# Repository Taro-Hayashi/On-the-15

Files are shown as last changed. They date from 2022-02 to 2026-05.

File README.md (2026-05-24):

# On the 15 ビルドガイド（[English](README_EN.md)）
- [キット内容](#キット内容)
- [レイアウトを決める](#レイアウトを決める)
- [はんだ付け](#はんだ付け)
- [組み立て](#組み立て)
- [キーのカスタマイズ](#キーのカスタマイズ)
- [そのほか](#そのほか)

## キット内容
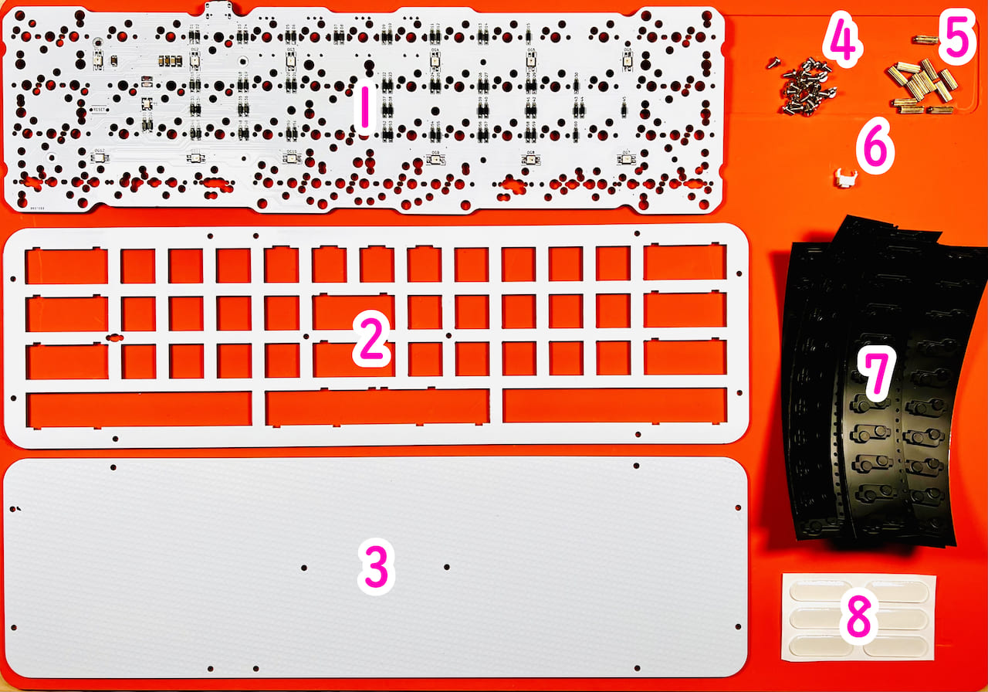
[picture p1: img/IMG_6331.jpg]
  
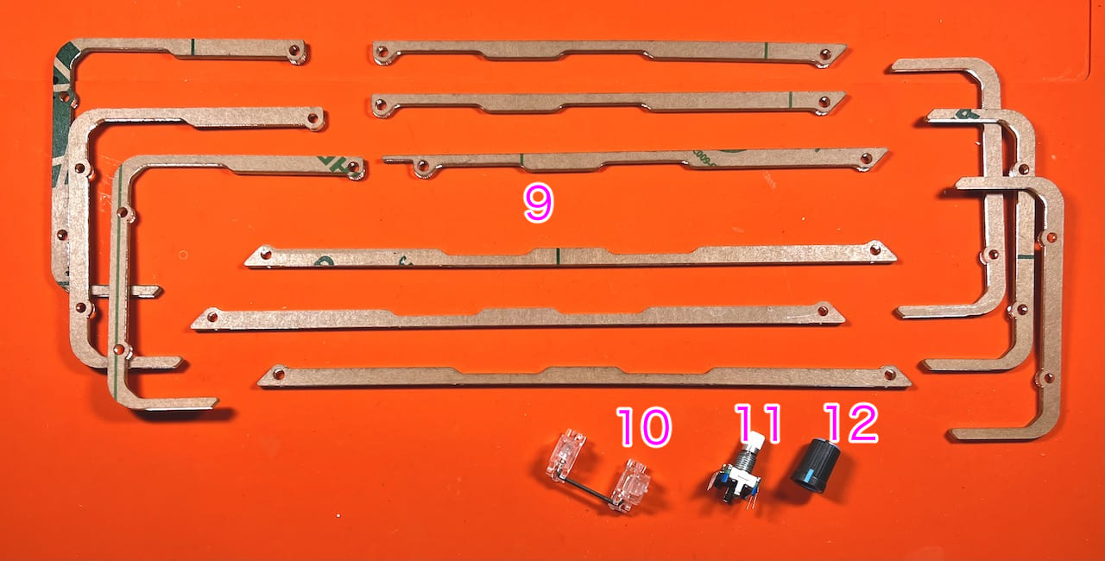
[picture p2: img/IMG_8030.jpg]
  
||部品名|数|
|-|-|-|
|1|メインボード|1|
|2|トッププレート|1|
|3|ボトムプレート|1|
|4|ネジ|22|
|5|スペーサー|11|
|6|リセットスイッチ|1|
|7|Cherry MX ホットスワップソケット|60|
|8|ゴム足|6|
|9|アクリルミドルプレート||
|10|2Uスタビライザー|1|
|11|ロータリーエンコーダー|1|
|12|ノブ|1|

### キット以外に必要なもの
|部品名|数|||
|-|-|-|-|
|キースイッチ|〜60|CherryMX互換|[遊舎工房](https://shop.yushakobo.jp/collections/all-switches/cherry-mx-%E4%BA%92%E6%8F%9B-%E3%82%B9%E3%82%A4%E3%83%83%E3%83%81) / [TALPKEYBOARD](https://talpkeyboard.net/?category_id=59cf8860ed05e668db003f5d) / [DailyCraftKeyboard](https://shop.dailycraft.jp/collections/mx-switches)|
|キーキャップ|〜60|CherryMX互換|[遊舎工房](https://shop.yushakobo.jp/collections/keycaps/cherry-mx-%E4%BA%92%E6%8F%9B-%E3%82%AD%E3%83%BC%E3%82%AD%E3%83%A3%E3%83%83%E3%83%97) / [TALPKEYBOARD](https://talpkeyboard.net/?category_id=59e2acfaed05e644fd004008)|
|Type-C ケーブル|1|||

### 追加できるもの
|部品名|||
|-|-|-|
|色違いアクリルプレート|-|[遊舎工房 - キーボードアクリルプレート](https://shop.yushakobo.jp/collections/services/products/keyboard_acrylic_plate?variant=43949129629927)|
|スタビライザー|2U、PCBマウント|[遊舎工房](https://shop.yushakobo.jp/collections/all-keyboard-parts/Stabilizer) / [TALPKEYBOARD](https://talpkeyboard.net/?category_id=5f884b9b3313d216eb50558a)|
|ロータリーエンコーダ|EC11/EC12/ロープロファイル|[遊舎工房](https://shop.yushakobo.jp/search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) / [TALPKEYBOARD](https://talpkeyboard.net/items/5f3f1a597df28129f2fd4b0f) / [DailyCraftKeyboard](https://shop.dailycraft.jp/products/encoder_low)|
|ノブ|外径19mmまで|[遊舎工房](https://shop.yushakobo.jp/products/3733) / [DailyCraftKeyboard](https://shop.dailycraft.jp/products/encoder_lowprofile_knob)|

専用のアクリルケースもあります。  
- [アクリルケースデータ](acrylic-case/README.md)
  - [fully-acrylic](acrylic-case/fully-acrylic/README.md)
  - [pcb-switchplate](acrylic-case/pcb-switchplate/README.md)

### 必要な工具
|工具名|
|-|
|はんだごて|
|こて先クリーナー（こて台）|
|鉛入りはんだ|
|ピンセット|
|精密ドライバー|

## レイアウトを決める
On the 15は60キーの格子配列キーボードですが、色のついたキーは長さを変更することができます。  
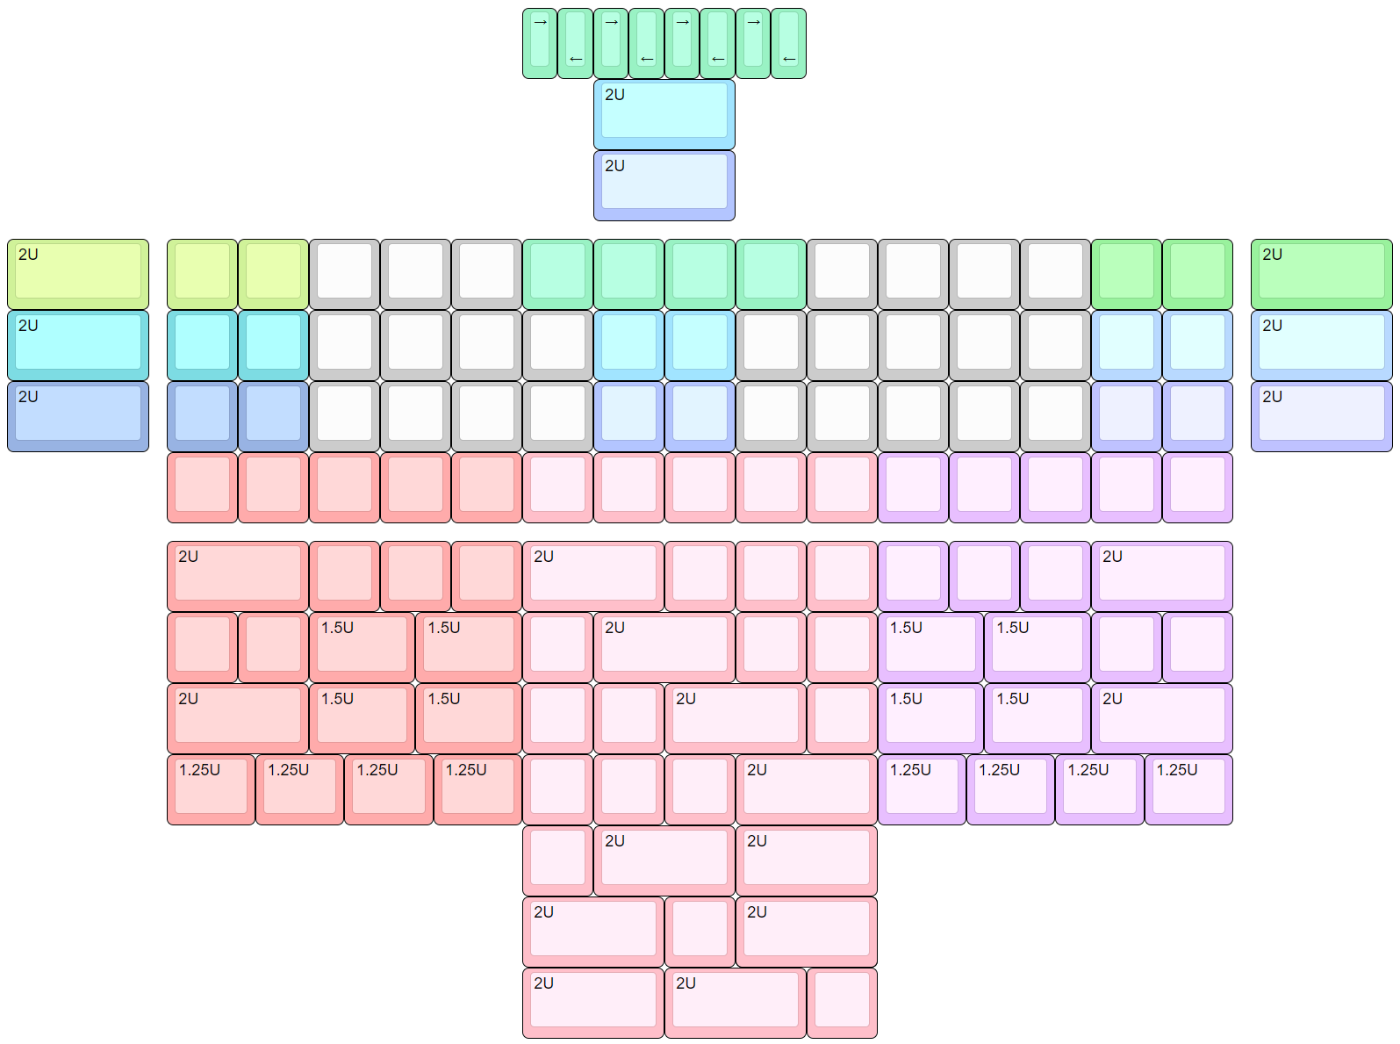
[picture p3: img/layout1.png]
  

ビルドガイドではこのようなレイアウトで組み立てます。　
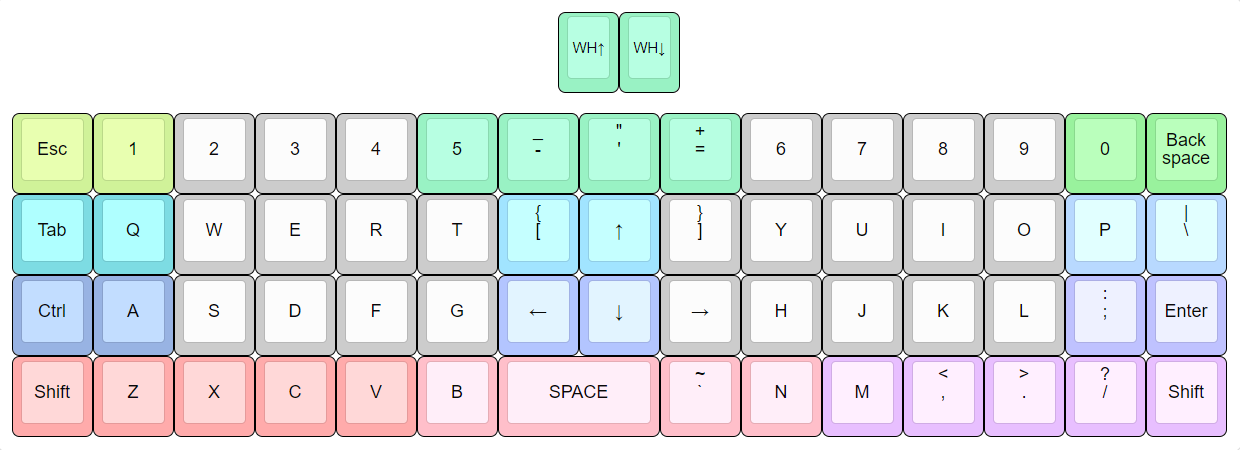
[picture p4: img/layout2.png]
  

## はんだ付け
### ソケットのはんだ付け
使うソケットのパッドに予備はんだをします。  
あらかじめ薄くはんだを乗せます。  
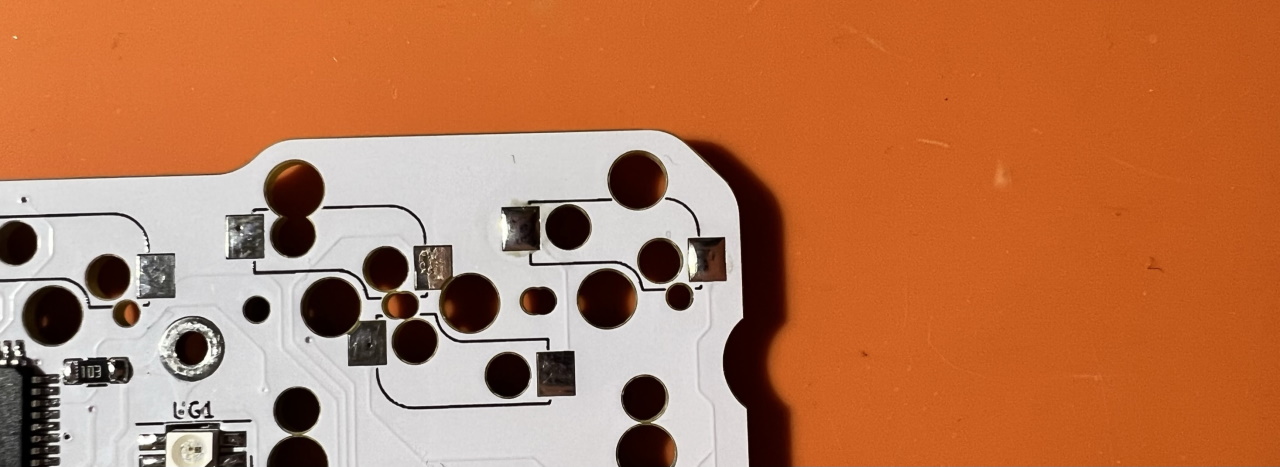
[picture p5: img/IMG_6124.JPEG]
  
ソケットを置いたらピンセットで押さえつけながらはんだを注いでいきます。入り組んでいて表面積が多いので多めに必要になります。
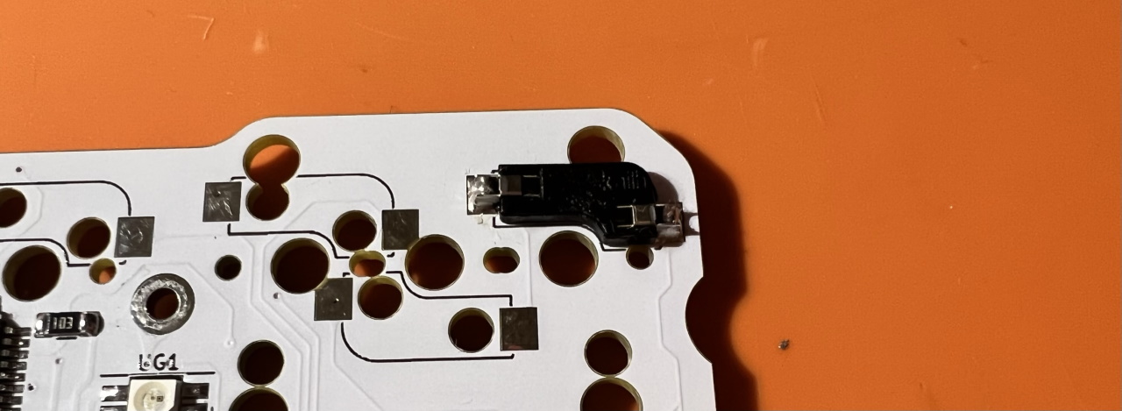
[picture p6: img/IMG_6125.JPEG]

慣れてきたら予備はんだを省略したり、一度に複数個置いてはんだ付けをすると楽になります。  
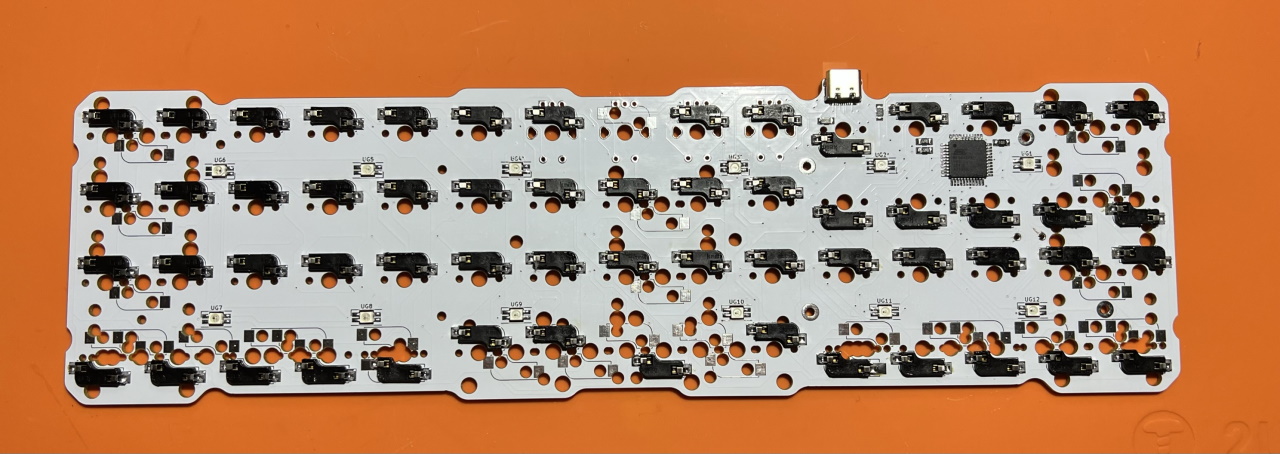
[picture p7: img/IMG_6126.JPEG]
  
### リセットスイッチのはんだ付け
表面左側のRESETと書いてあるところにリセットスイッチを差して裏からはんだ付けします。  
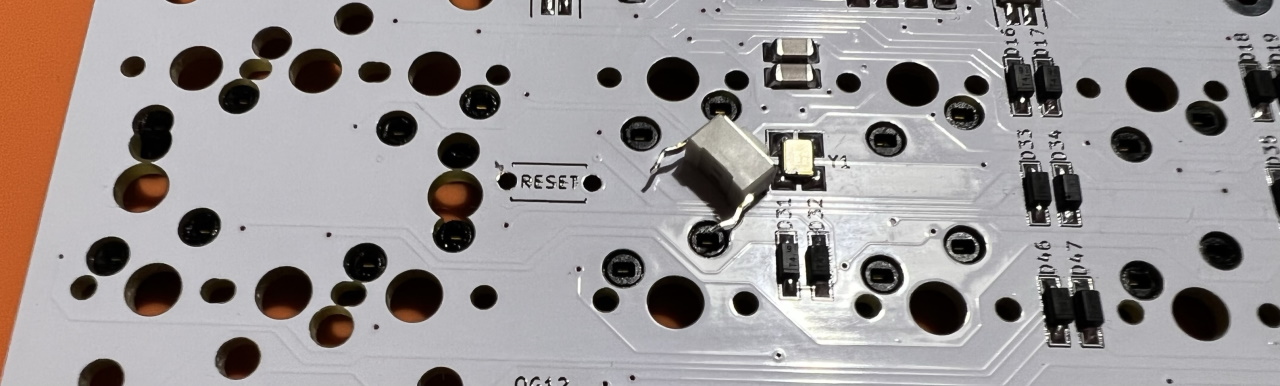
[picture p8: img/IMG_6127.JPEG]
  

### ロータリーエンコーダーのはんだ付け
足を折らないようにホールに通して裏からはんだ付けします。  
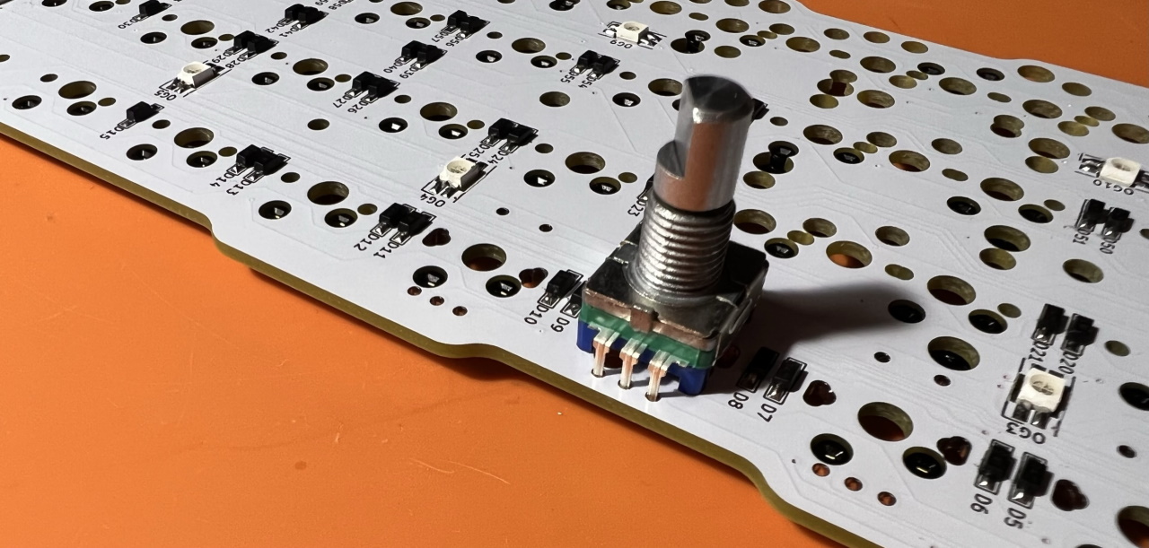
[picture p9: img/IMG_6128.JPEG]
   

### テストファームウェアの書き込み
テスト用のファームウェアをこちらからダウンロードしてください。
- https://remap-keys.app/catalog/9bQPDxdkX8xgflHlsR9p/firmware

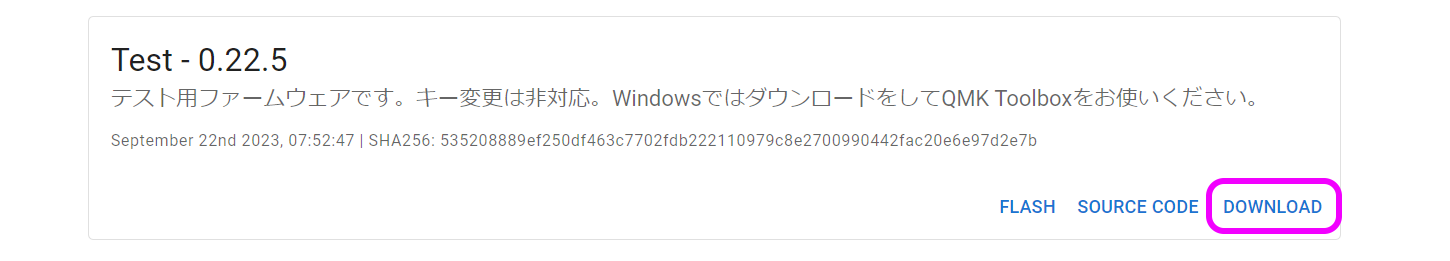
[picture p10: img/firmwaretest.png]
 

QMK Toolboxのreleaseページから最新版をダウンロードしてインストールください。  
- [Releases・qmk/qmk_toolbox](https://github.com/qmk/qmk_toolbox/releases)

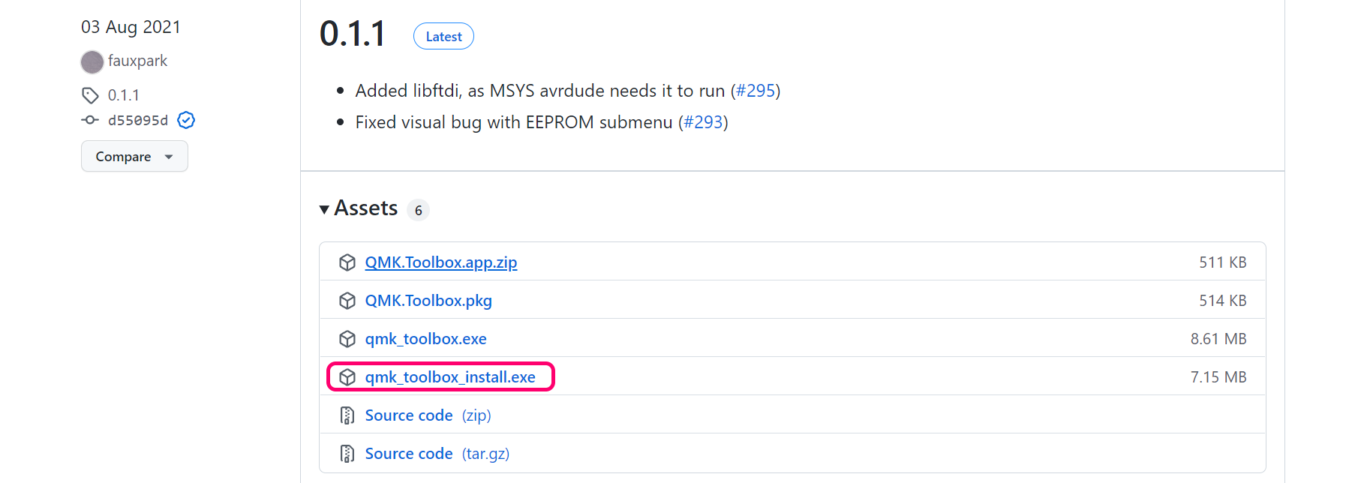
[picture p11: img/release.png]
  
起動したらOpenを押してダウンロードしたファームウェアを指定し、はんだ付けしたリセットボタンを押します。  
   
新しく黄色の文字が出てきたらFlashを押します。  
  

Thank youの後に黄色い文字が出たら更新完了です。  
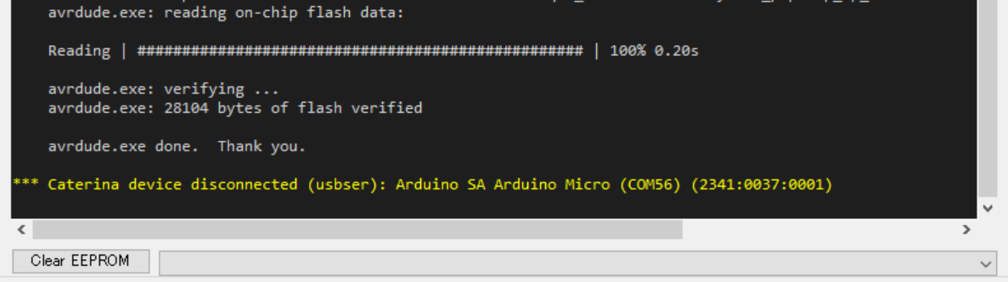
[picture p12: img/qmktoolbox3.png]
   

### 動作確認
キースイッチを差したり裏をピンセットで短絡したりして動作確認をします。  
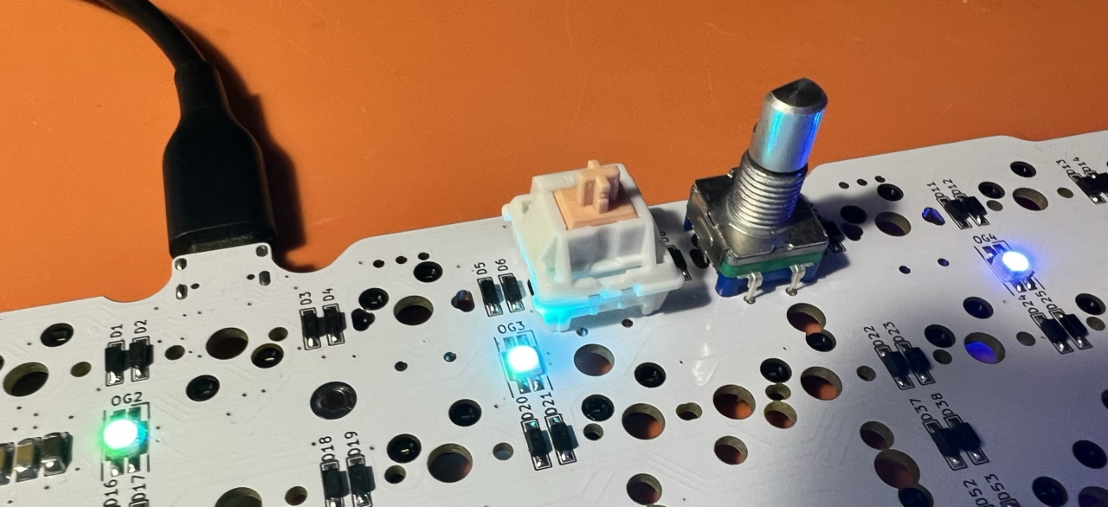
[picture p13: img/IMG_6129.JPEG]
   
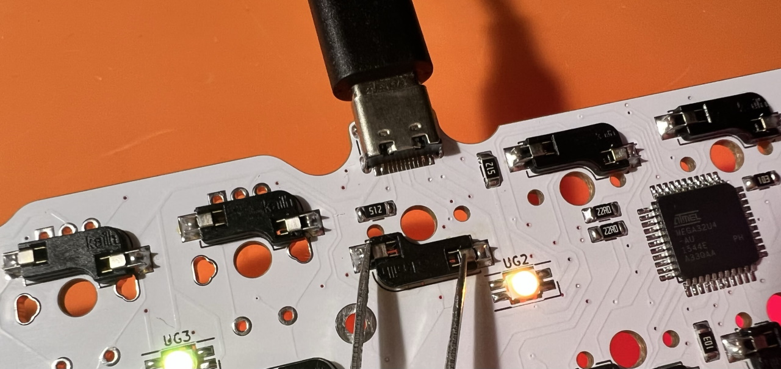
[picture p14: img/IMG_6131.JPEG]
   

## 組み立て
### スタビライザーを組み立てる
スタビライザーがあると2Uのキーの押下が安定します。無くても使えるのでお好みでお使いください。  
ねじ止め式のスタビライザーは縦に二つ並べておくことはできないので使う場所に気をつけるかスナップ型のスタビライザーを使ってください。  

小さい方のパーツの穴が二つ開いている側を、大きいパーツの穴が開いている方向に合わせて組み合わせます。  
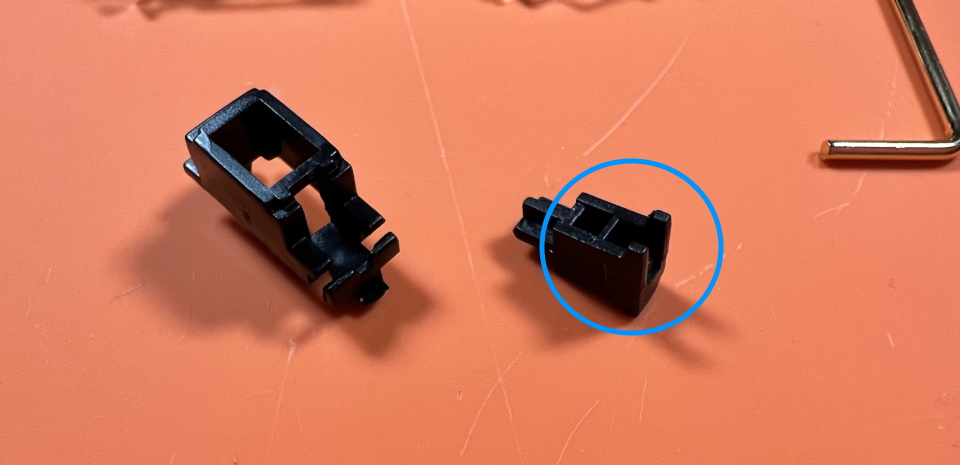
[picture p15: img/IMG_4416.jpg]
  
金属の棒を下の穴に差し込みツメにパチっと音がするまで押し込んで完成です。  
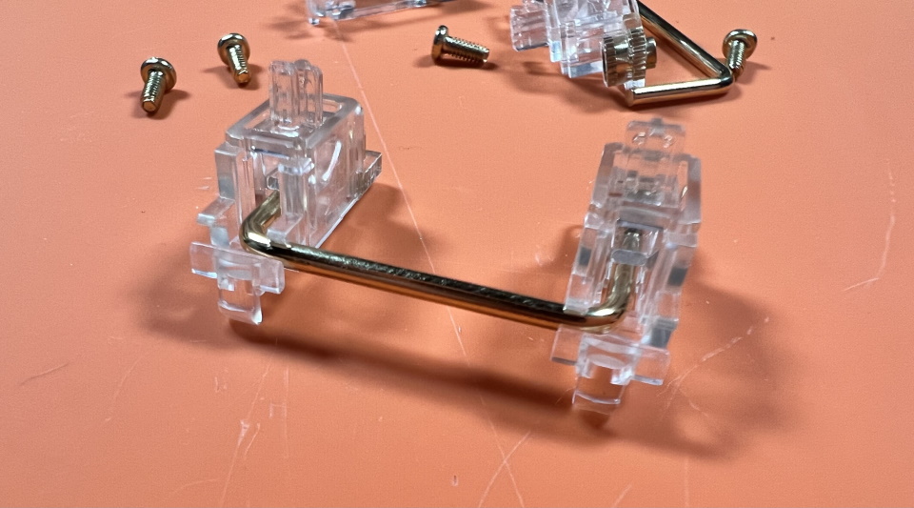
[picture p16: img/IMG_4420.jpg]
    
基板の大きい方の穴にツメをひっかけながら取り付けます。  
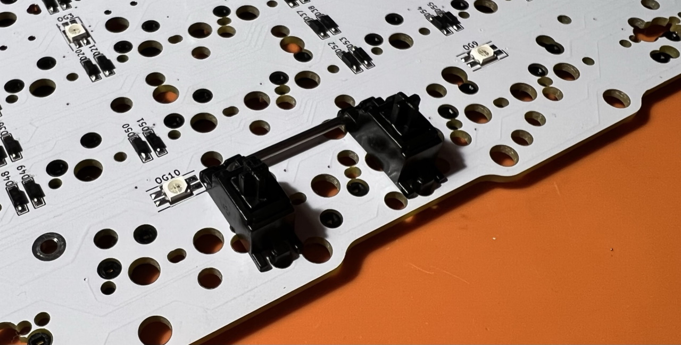
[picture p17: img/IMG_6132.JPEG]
  

### メインボードにトッププレートを取り付ける
トッププレートの裏側にスペーサーをねじ止めします。  
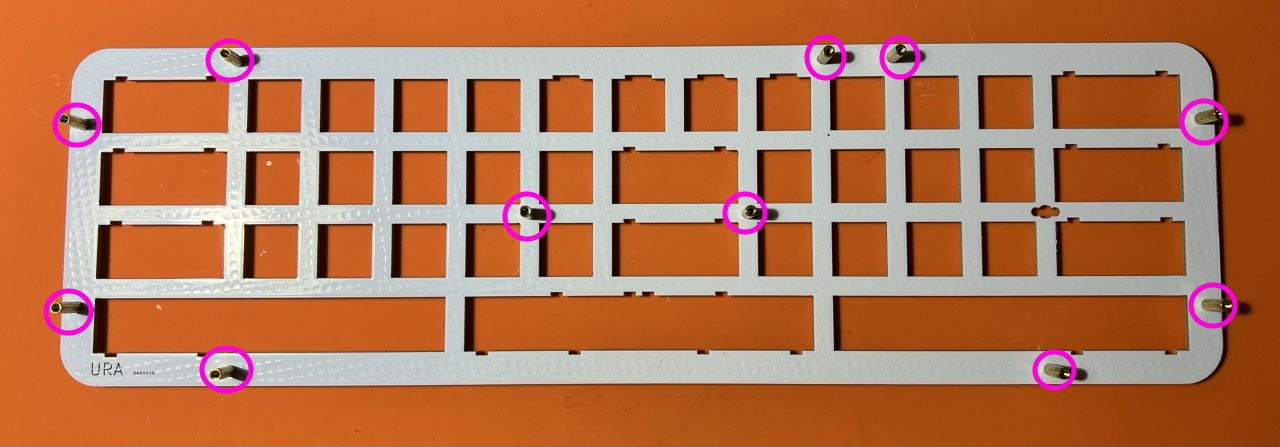
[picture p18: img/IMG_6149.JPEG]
   
メインボードにかぶせて、4隅のスイッチをはめ込みます。  
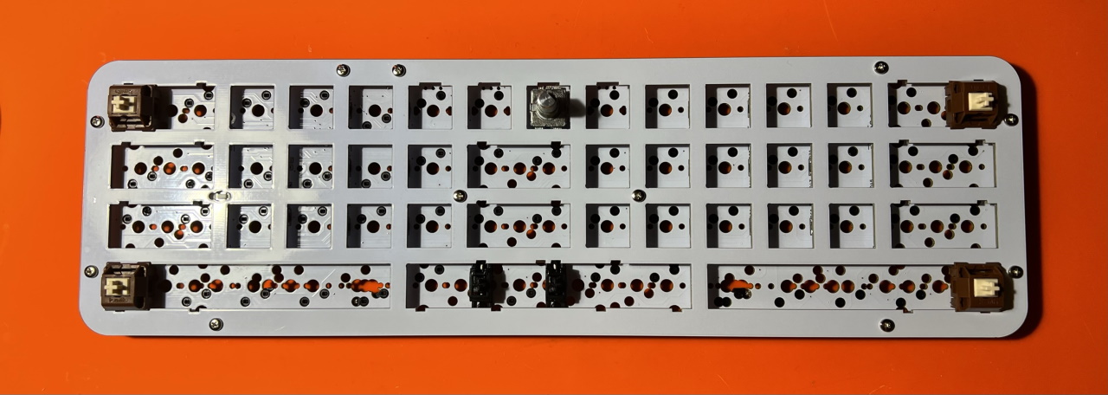
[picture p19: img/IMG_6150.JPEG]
   
すべてのスイッチを差し込みました。  
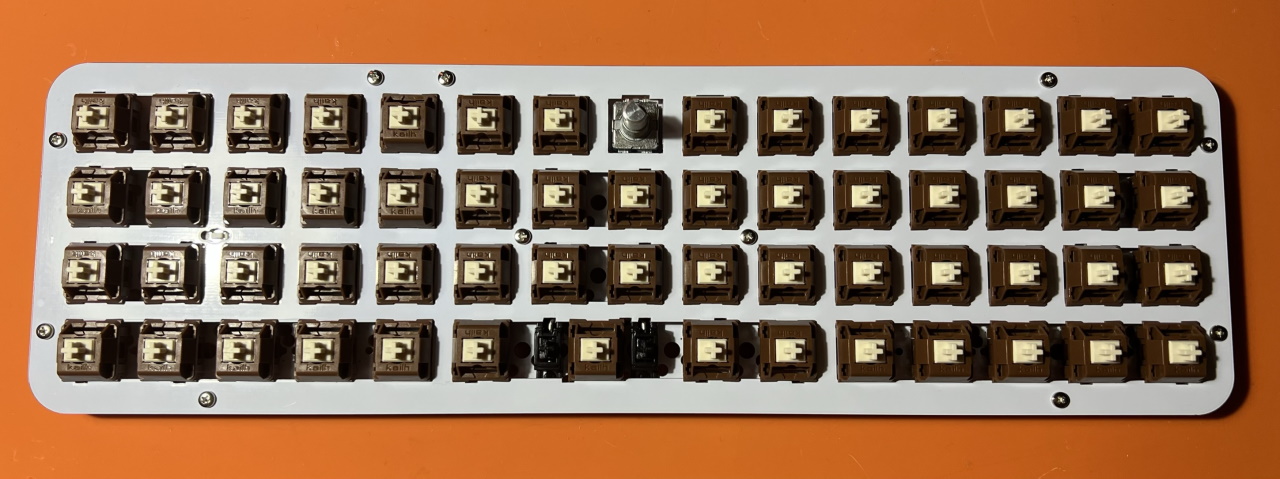
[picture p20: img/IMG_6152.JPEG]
  

### アクリルプレートを挟み込む
画像のような形で3段にして挟み込みます。  
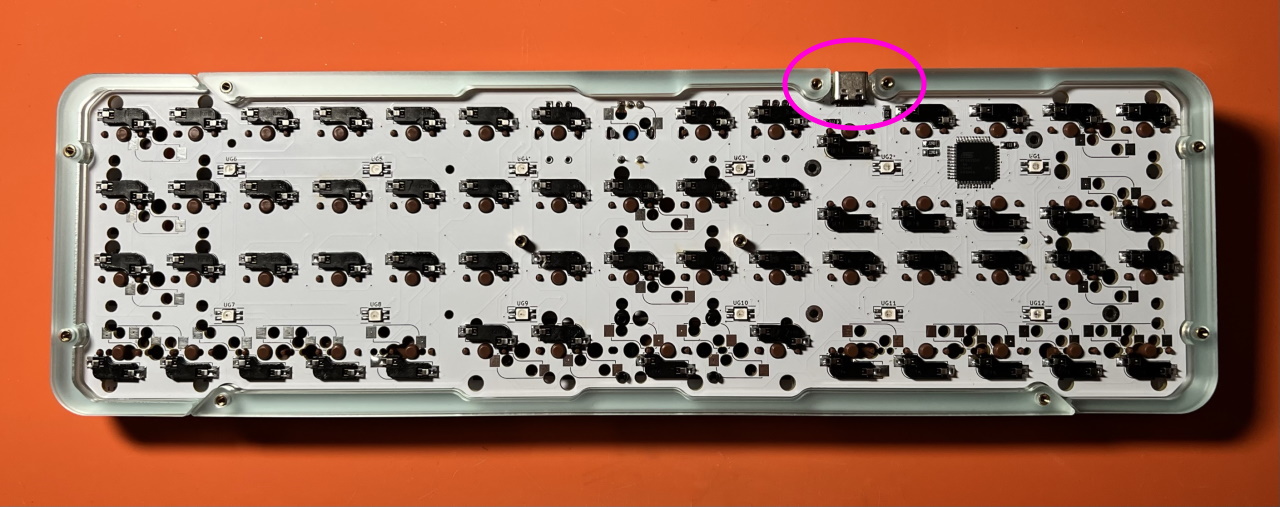
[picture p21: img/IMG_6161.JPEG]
  

### バックプレートを取り付ける
バックプレートをねじ止めしてゴム足を貼ります。  
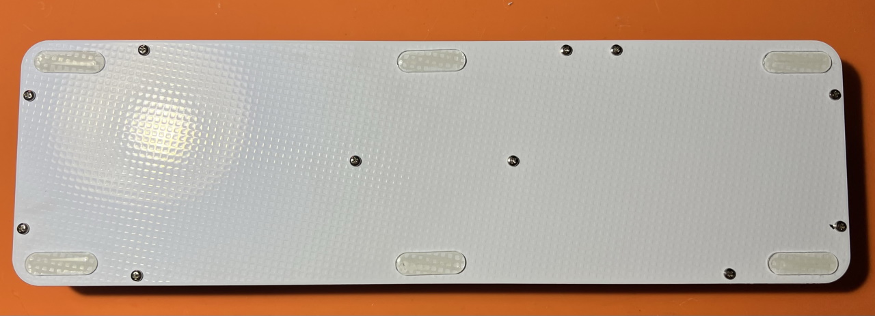
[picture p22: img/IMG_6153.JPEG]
  
キーキャップを付けたら完成です。  
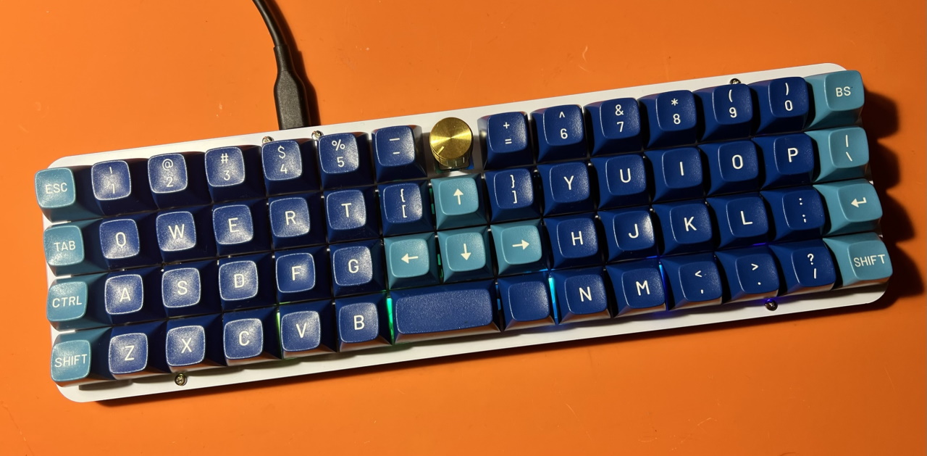
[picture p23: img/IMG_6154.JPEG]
  

### Remap用ファームウェアの書き込み
Remap用のファームウェアをこちらからダウンロードして、さきほどと同様に書き込んでください。
- https://remap-keys.app/catalog/9bQPDxdkX8xgflHlsR9p/firmware

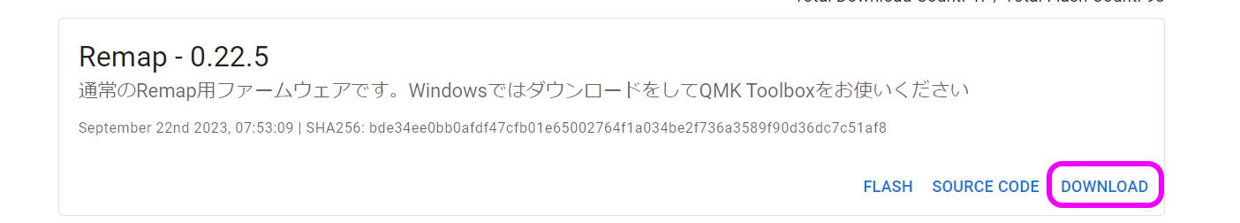
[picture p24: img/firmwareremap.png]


## キーのカスタマイズ
こちらのサイトにアクセスしてください。
- Remap https://remap-keys.app

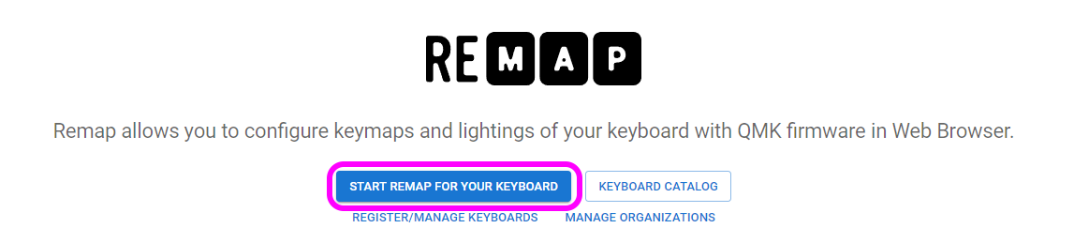
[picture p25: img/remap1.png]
  
左を選んで進んでいくとダイアログが出てキーボードを選択できます。  
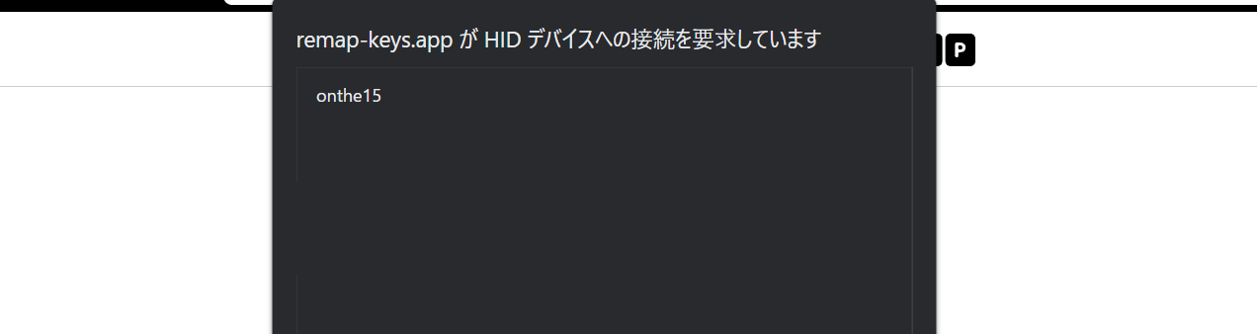
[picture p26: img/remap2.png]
  
選択して接続してください。
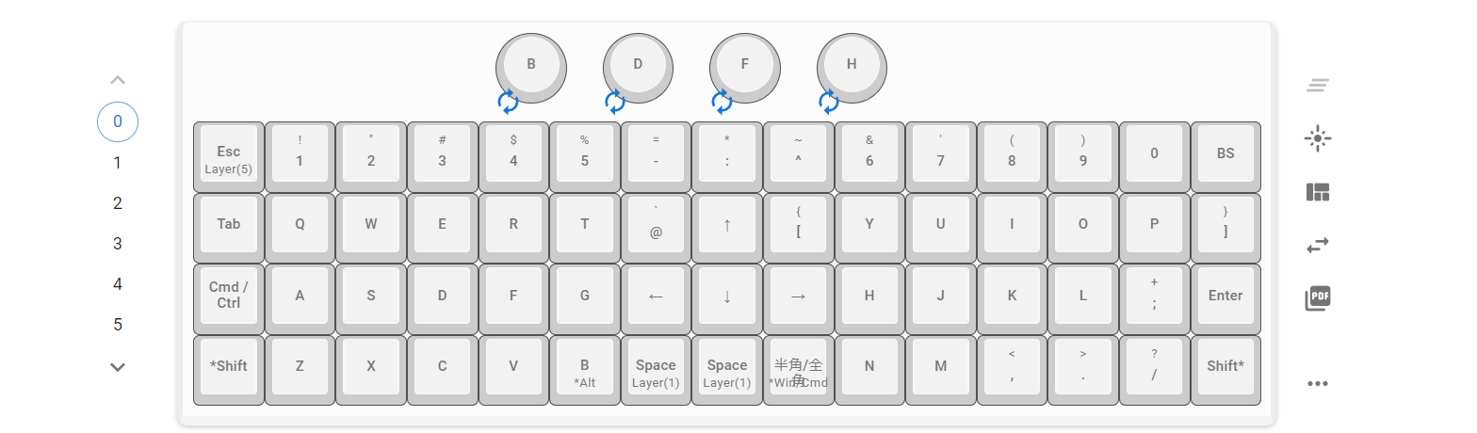
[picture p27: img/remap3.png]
  

### キーマップの保存と復元
⇔アイコンで作ったキーマップを保存することができます。  
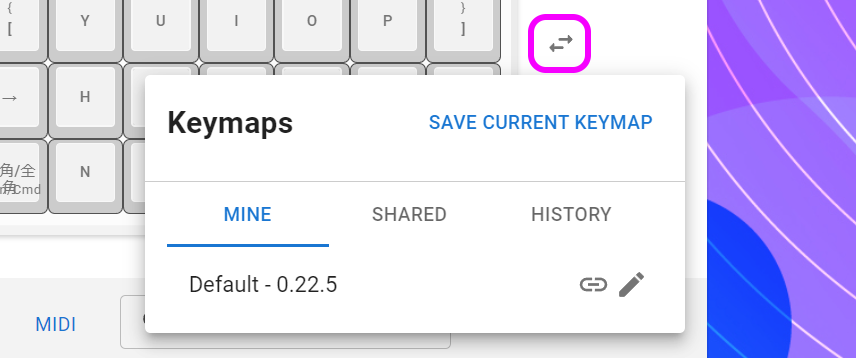
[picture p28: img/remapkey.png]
  
作ったキーマップを共有することもできるので是非お試しください。

### レイアウトを変える
キーボードの右のこのボタンでレイアウトを変えることができます。  
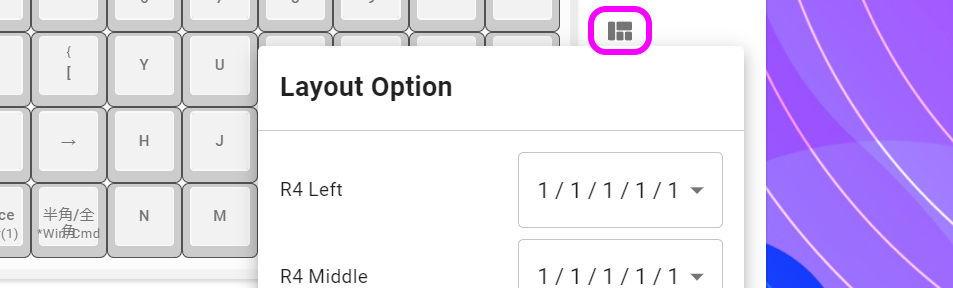
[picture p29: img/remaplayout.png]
  

### キーを設定する
下のキー一覧からドラッグアンドドロップし、変更が終わったら右上のflashボタンを押すと反映されます。  
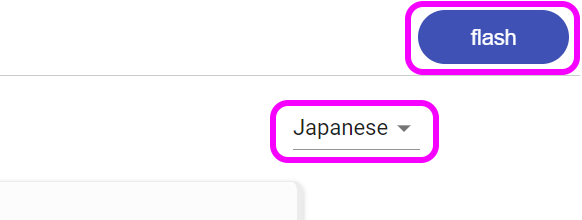
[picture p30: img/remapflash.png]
  
また、USキーボードとJISキーボードはFlashの下のプルダウンから変更できます。OSの設定に合わせてください。

### 修飾キーとの組み合わせを設定する
上のキーボードのキーをクリックすると設定画面になります。
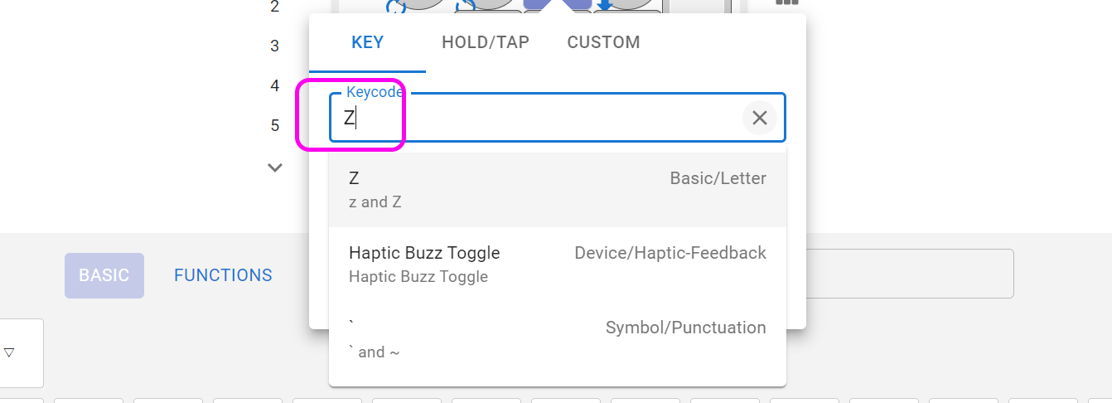
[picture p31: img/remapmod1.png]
  
修飾キーと同時押ししたいキーを検索し、同時押ししたい修飾キーにチェックを入れます。
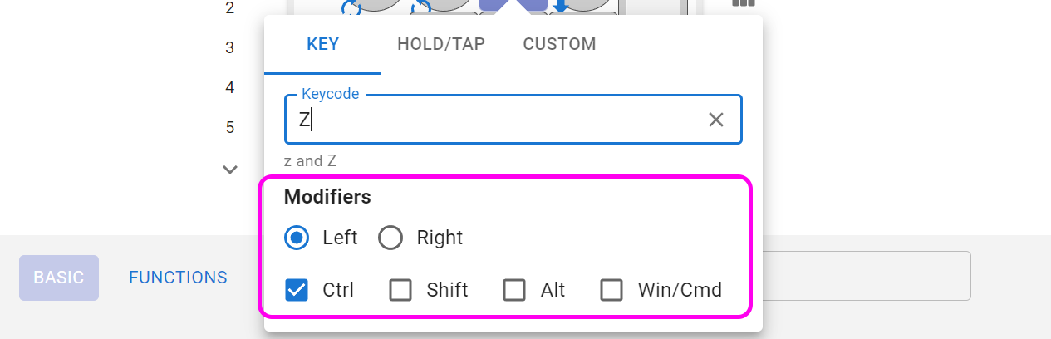
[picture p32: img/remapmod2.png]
  

Hold-Tapもここから設定できます。

### ロータリーエンコーダーを設定する
丸いキーの左下をクリックすると時計回り、反時計回りを切り替えることができるので、それぞれにキーを割り当てます。
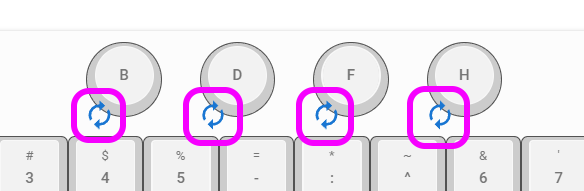
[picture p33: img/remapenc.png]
  

### 特殊なキーを設定する
FUNCTIONSタブのVIA USER KEYにあらかじめ用意されたショートカットキーがあります。
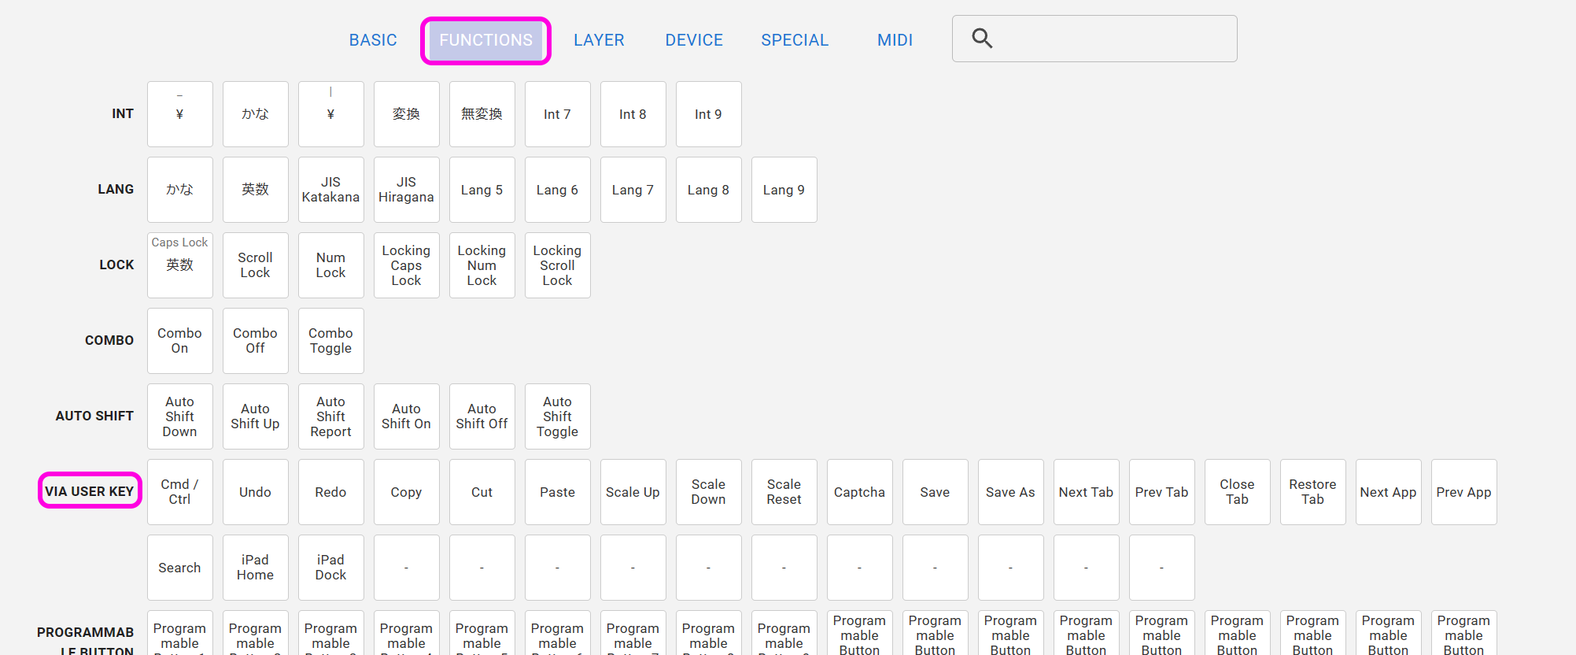
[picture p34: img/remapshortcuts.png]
  

### LEDを調整する
このボタンで発光方法を変更することができます。
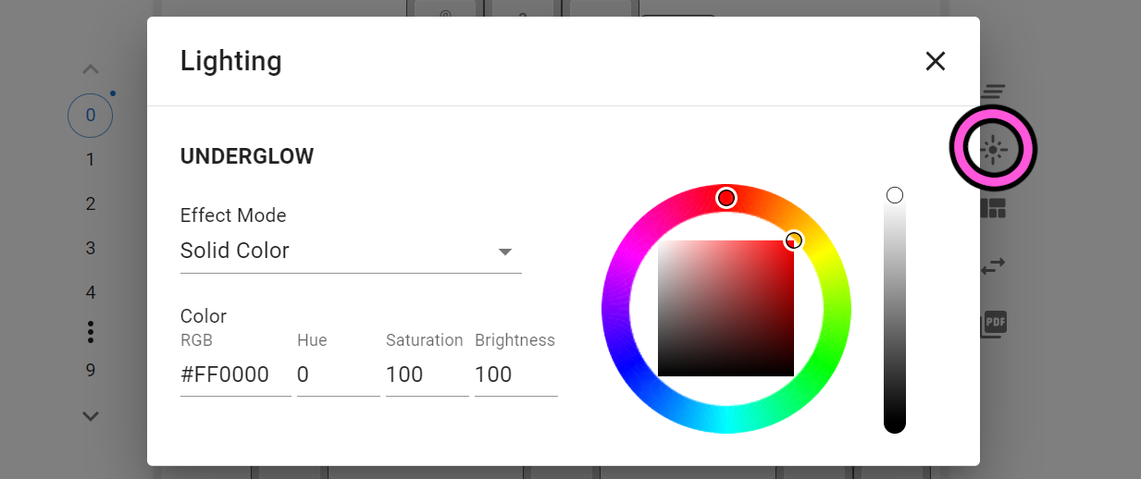
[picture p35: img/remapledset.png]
  

## そのほか
### リセットスイッチの押し方
こちらの隙間からドライバーやピンセットを差し込むことで押すことができます。
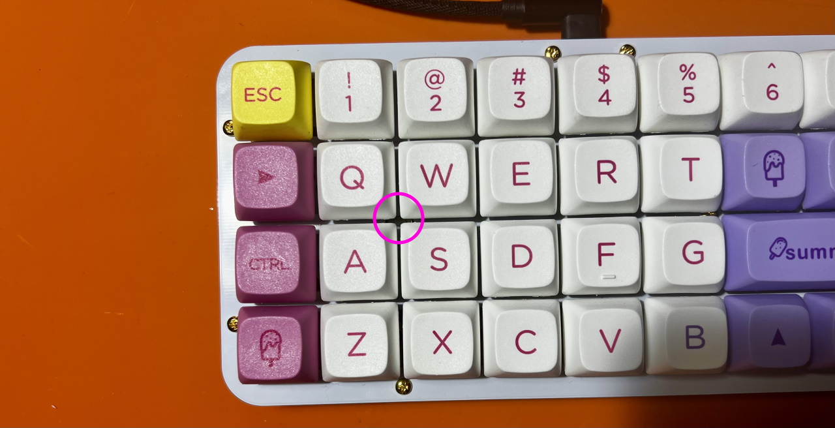
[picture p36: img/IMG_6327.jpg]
  

### ファームウェアのコード
https://github.com/Taro-Hayashi/qmk_firmware/tree/tarohayashi/keyboards/tarohayashi/onthe15

### プレートのデータ
- [onthe15_plates.zip](https://github.com/Taro-Hayashi/On-the-15/releases/download/0.22.3/onthe15_plates.zip)

### アクリルケースのデータ
- [fully-acrylic](acrylic-case/fully-acrylic/README.md)
- [pcb-switchplate](acrylic-case/pcb-switchplate/README.md)

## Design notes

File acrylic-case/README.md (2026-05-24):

# On the 15 アクリルケース

On the 15 用のアクリルケースデータです。

## fully-acrylic

アクリル積層ガスケットマウントケースです。

- [ビルドガイド](fully-acrylic/README.md)
- [発注データ](fully-acrylic/data.md)
- [プレート一覧](fully-acrylic/plates.md)

## pcb-switchplate

FR4スイッチプレートを使うアクリル積層ケースです。

- [ビルドガイド](pcb-switchplate/README.md)

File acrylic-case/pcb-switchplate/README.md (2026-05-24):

# On the 15 アクリル積層ケース

## キット内容

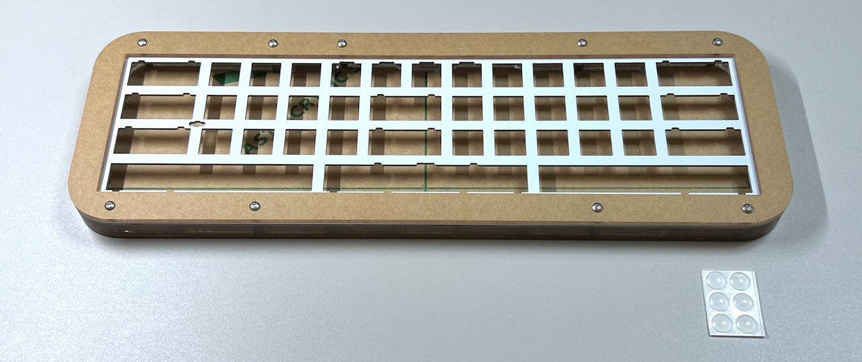
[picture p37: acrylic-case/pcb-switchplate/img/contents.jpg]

||||
|-|-|-|
|トッププレート|1|アクリル|
|スイッチプレート|1|FR4|
|ミドルプレート|3|アクリル|
|ボトムプレート|1|アクリル|
|ねじ|18|6mm|
|スペーサー|9|8mm|
|ゴム足|6||

## キット以外に必要なもの

|||
|-|-|
|[On the 15](https://github.com/Taro-Hayashi/On-the-15/blob/main/README.md)|1|
|キースイッチ|〜60|
|キーキャップ|〜60|
|Type-C USBケーブル|1|
|（オプション）スタビライザー|1|
|（オプション）ロータリーエンコーダーとノブ 〜4|1|

## 組み立て方
> [!NOTE]  
> On the 15のPCBの組み立て方はOn the 15のビルドガイドをご覧ください  
> - https://github.com/Taro-Hayashi/On-the-15/blob/main/README.md

組み立てられた状態のケースを一度分解します。  
  
ケースに付属のスイッチプレートを挟み込むように、On the 15のメインボードにキースイッチを差し込みます。  
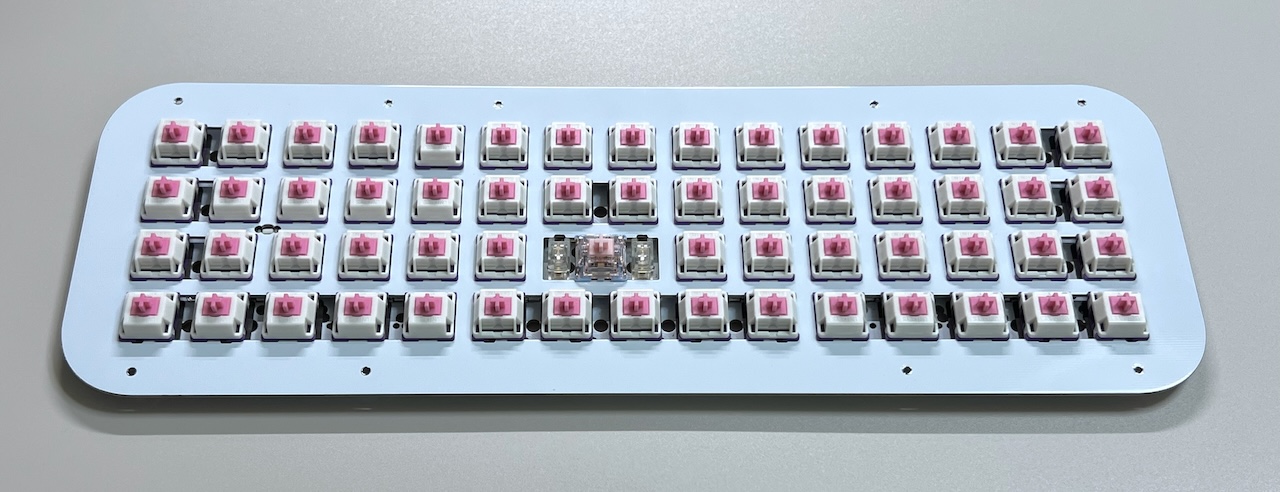
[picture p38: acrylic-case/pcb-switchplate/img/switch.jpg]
  
  
トッププレートをスイッチプレートにのせ、裏返してねじとスペーサーで止めます。  
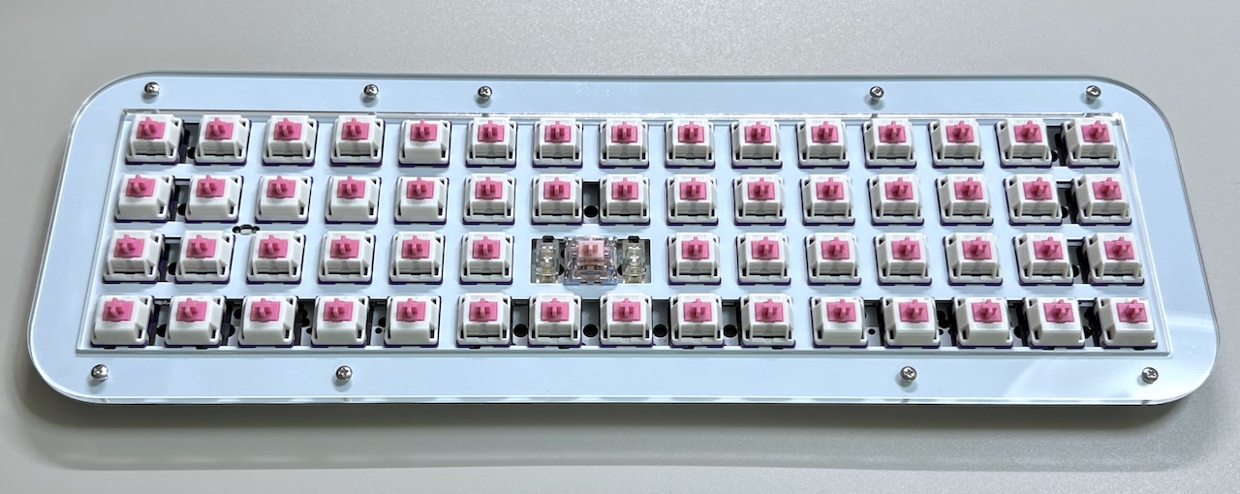
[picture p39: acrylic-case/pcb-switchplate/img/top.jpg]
  
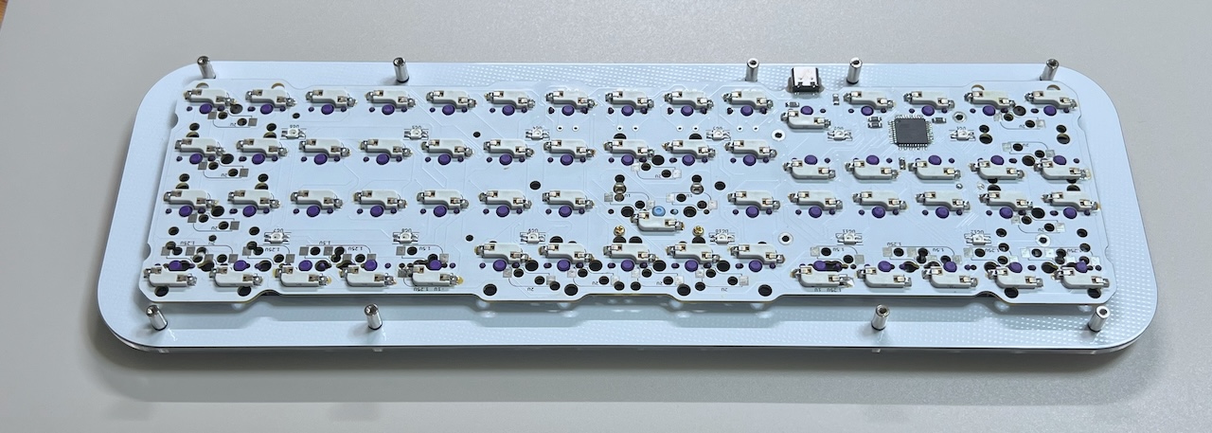
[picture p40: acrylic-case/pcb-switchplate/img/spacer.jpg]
  
  
ミドルプレートを3枚乗せます。  
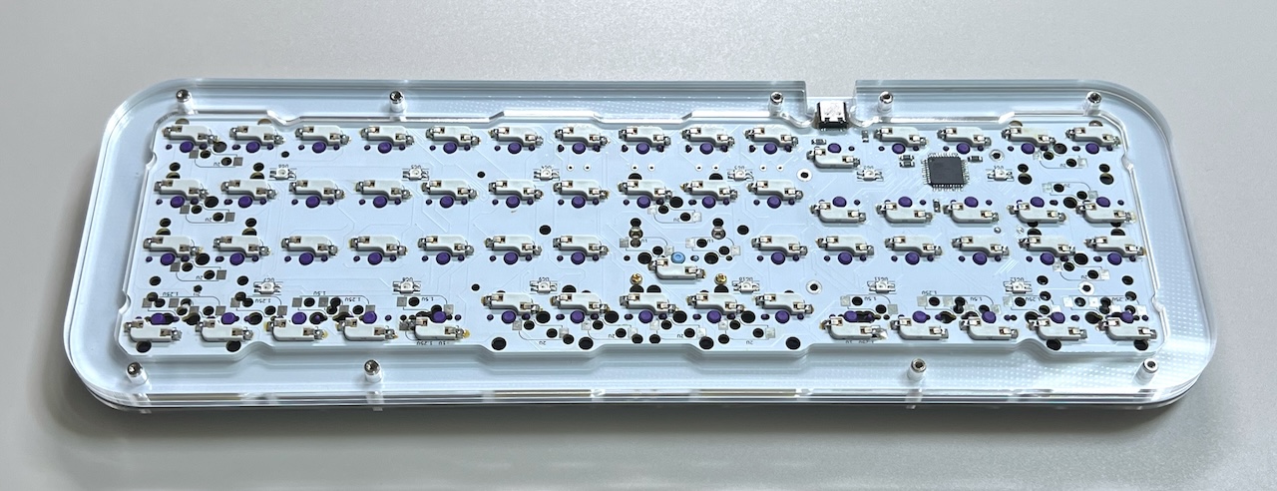
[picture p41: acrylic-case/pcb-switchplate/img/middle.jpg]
  
   
ボトムプレートをねじで止め、ゴム足を貼ります。  
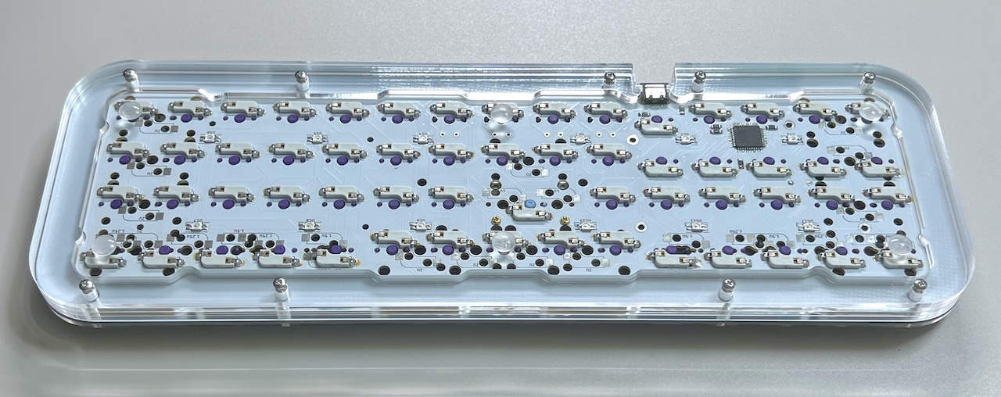
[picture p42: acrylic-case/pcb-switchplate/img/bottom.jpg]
  
  
表でねじを少し締め直し、キーキャップを付けたら完成です。  
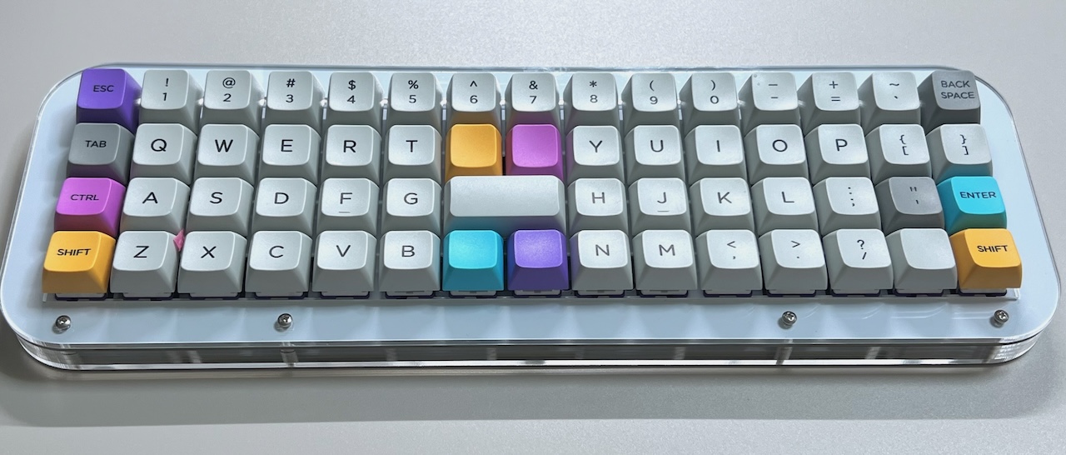
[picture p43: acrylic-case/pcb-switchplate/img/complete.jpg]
  

## デザインデータ
- [デザインデータ](../../KiCad/pcb-switchplate/)

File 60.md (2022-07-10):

# 60%ケース対応パーツ ビルドガイド

## キット内容
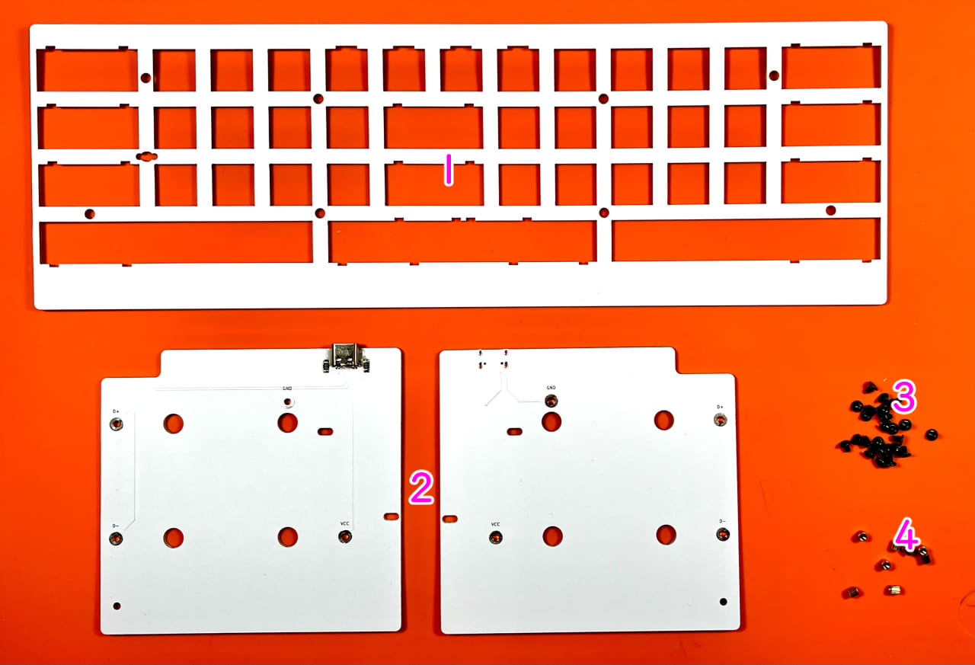
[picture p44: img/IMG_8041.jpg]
  
||部品名|数|
|-|-|-|
|1|60%ケース用トッププレート|1|
|2|マウントプレート|2|
|3|ネジ|21|
|4|スペーサー|8|

### メインボードをケースに設置する
マウントプレートにスペーサーをねじ止めします。  
Type-Cのコネクタが付いている方を左側にして、画像のように付けてください。  
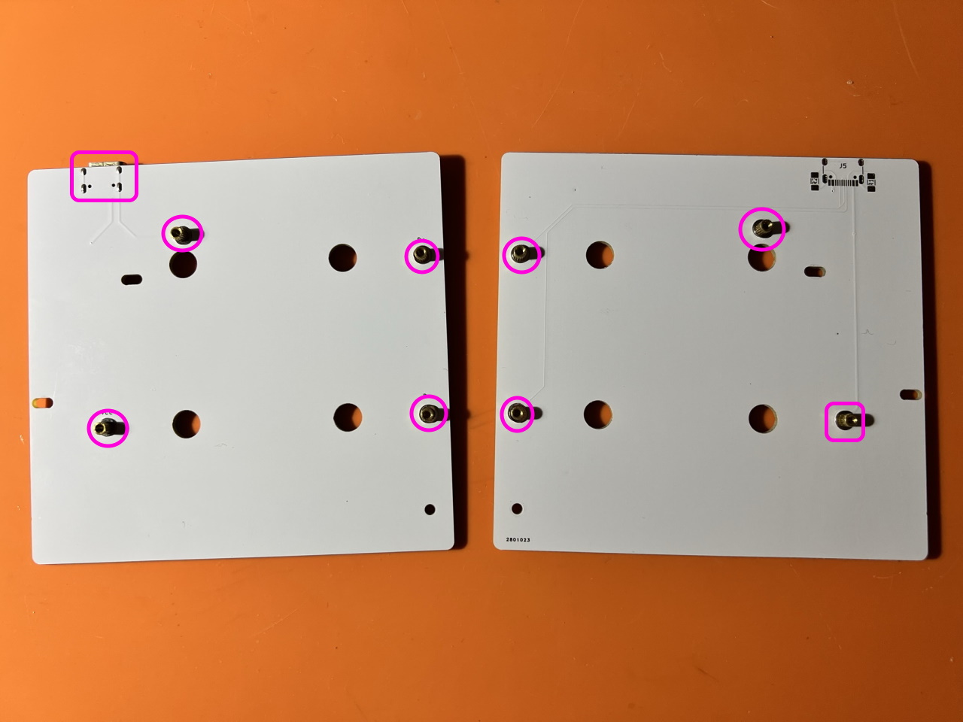
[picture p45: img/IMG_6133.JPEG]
   
ケースにマウントプレートをねじ止めします。  
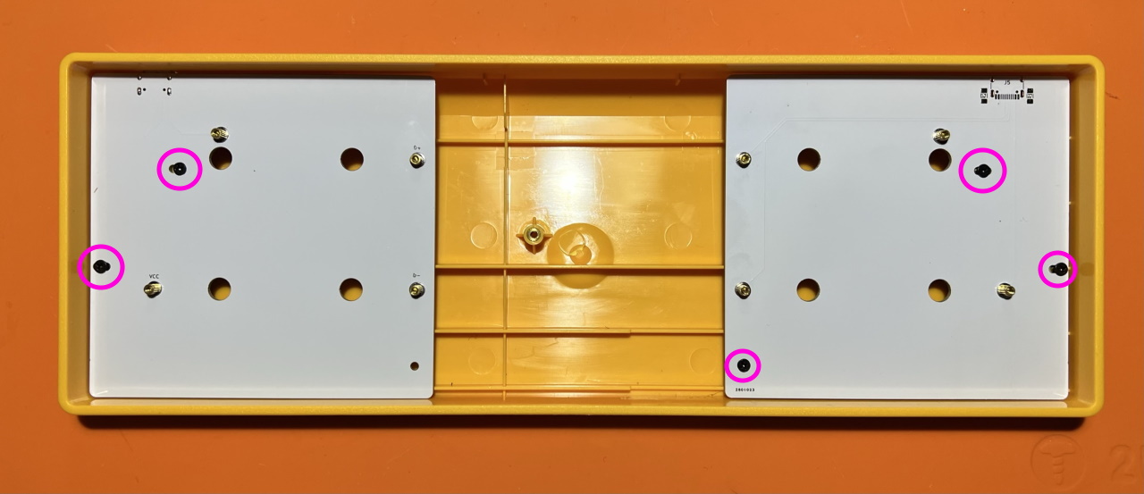
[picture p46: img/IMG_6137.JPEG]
   
メインボードをねじ止めします。  
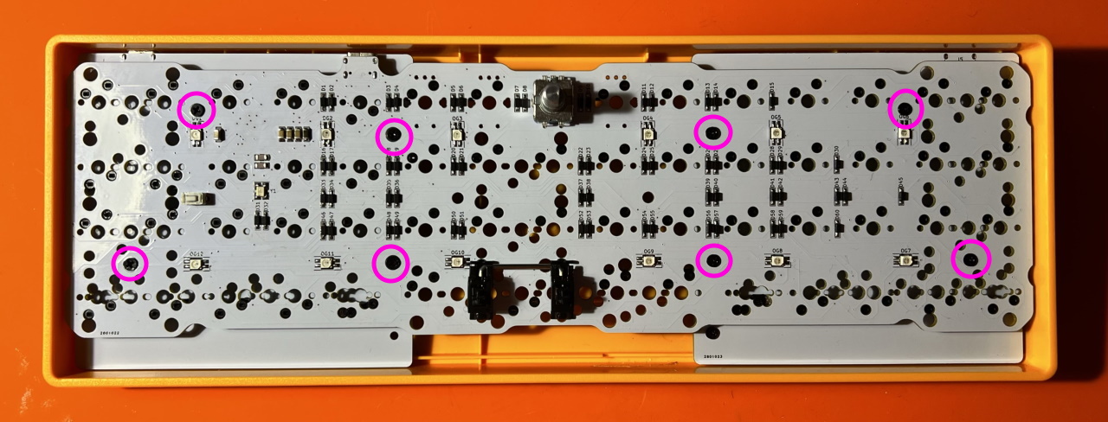
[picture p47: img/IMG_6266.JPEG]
   

### トッププレートを取り付ける
メインボードとトッププレートの位置を合わせて、まずは4隅にキースイッチをはめ込みます。  
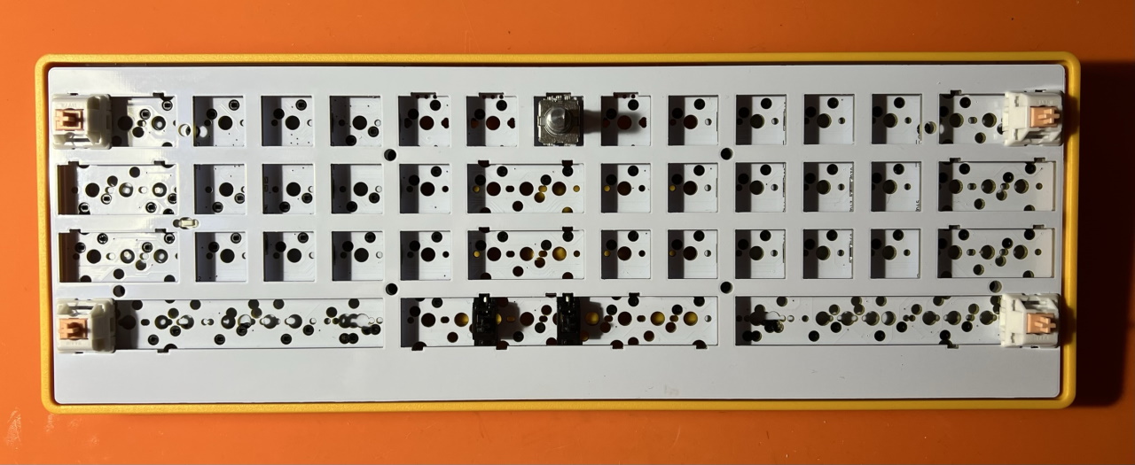
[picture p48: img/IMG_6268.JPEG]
   
メインプレートにはスイッチのツメにひっかかるように、メインボードに差す時はピンが曲がらないように気を付けます。  
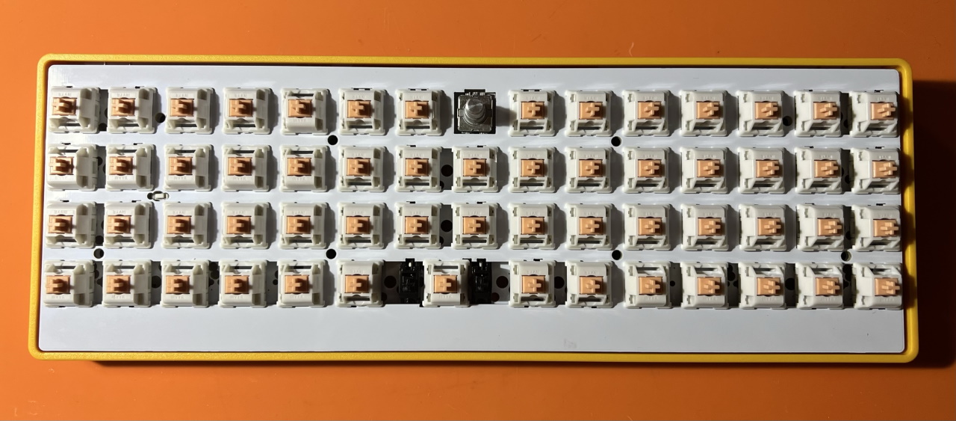
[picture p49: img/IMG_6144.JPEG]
   
キーキャップを付けたら完成です。
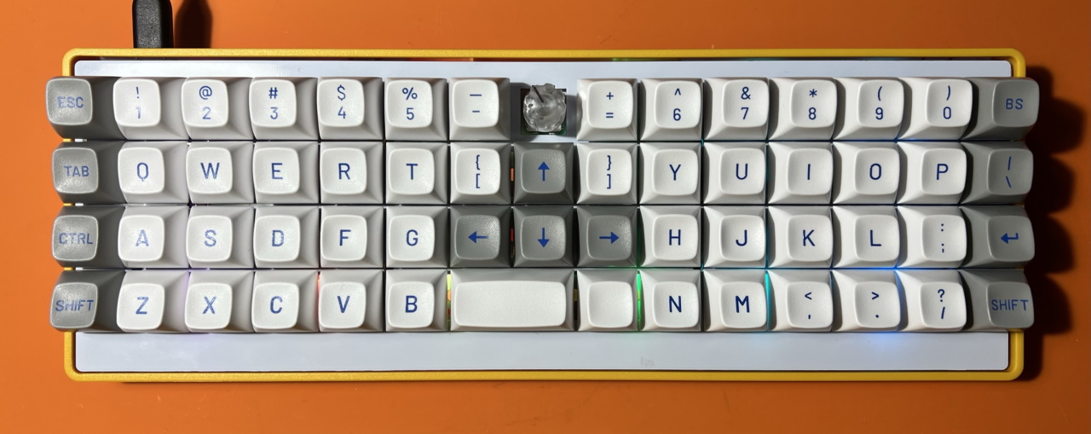
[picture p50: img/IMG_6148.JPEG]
 
LEDをオフにしたい場合は左上(ESC)のキーを押しながらその下のキーを押してください。

### 販売ページ
- BOOTH: [On the 15（B-Stock）、60%ケース対応パーツ](https://tarohayashi.booth.pm/items/3672079)

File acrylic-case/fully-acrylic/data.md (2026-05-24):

# プレートの発注について

## アクリルプレート
### 発注先
積層構造に向いた押出材を選べる、遊舎工房さんやEmerge+さんに発注することをお勧めします。  
- [遊舎工房](https://shop.yushakobo.jp/products/lasercut)
- [Emerge+](https://www.emergeplus.jp)  

### 発注データ
厚みは3mmです。遊舎工房さん向けはA4と450x300mmの2枚、Emerge+さん向けは300x600mmで発注してください。
- [発注データ](../../KiCad/fully-acrylic/)

kicad用ファイル、Inkscape用ファイルが入っているので各社A4サイズのテンプレートにコピペし、指定通りにレイヤーや線の色を修正して見積もりにかけてください。  
階層別のデータはパーツを上手く配置すれば他のアクリルパーツと一緒に発注したり、特定の層だけ色を変えたりすることができます。  

## トッププレート
kicad用のファイルとALLPCBさん向けのガーバーファイルを公開しています。
- [発注データ](../../KiCad/fully-acrylic/)
- [ALLPCB](https://www.allpcb.com)
  
問題があった時はご自身で対処してください。  
プレートのデータ及び注文品はご自由に複製、改変、頒布していただけます。

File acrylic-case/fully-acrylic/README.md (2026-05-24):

# On the 15 アクリル積層ガスケットマウントケース
- [ご注意](#ご注意)
- [キット内容](#キット内容)
- [組み立て](#組み立て)

## ご注意
- 組み立てにはOn the 15（[遊舎工房](https://shop.yushakobo.jp/products/4994)、[BOOTH](https://tarohayashi.booth.pm/items/3672079)）のメインボードが必要です。
- 自分で発注するとお好きな色のアクリル、ネジで制作可能です。

## キット内容
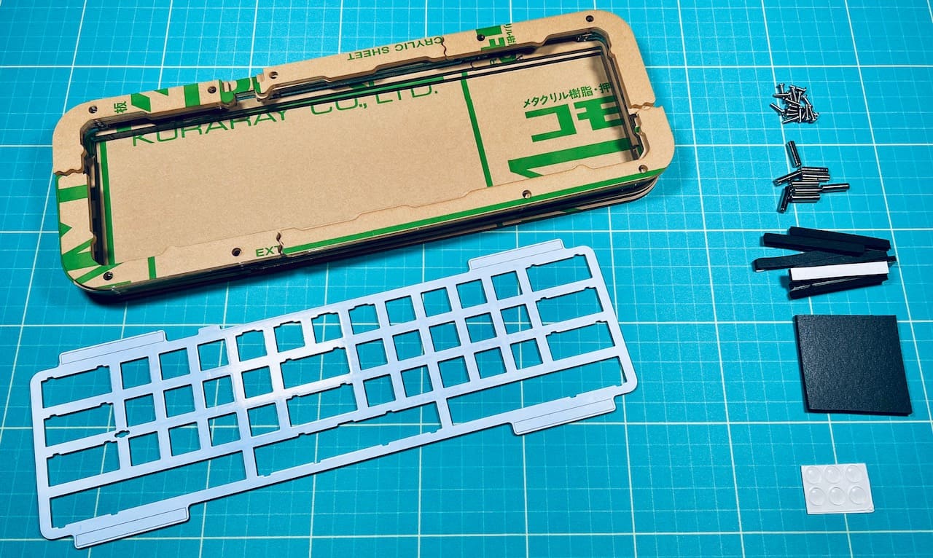
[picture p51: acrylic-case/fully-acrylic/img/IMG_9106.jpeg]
  
|部品名|数|入手先|
|-|-|-|
|アクリルプレート|[図面データ](data.md)|[遊舎工房](https://shop.yushakobo.jp/collections/services/products/lasercut)、[工房Emerge+](https://www.emergeplus.jp)等|
|トッププレート|[図面データ](data.md)|各種PCB製造業者|
|8mmM2ネジ|18|[遊舎工房](https://shop.yushakobo.jp/products/a0800n2?_pos=2&_sid=6d67644cd&_ss=r&variant=37665433026721)、[ヒロスギネット](https://www.hirosugi-net.co.jp/shop/g/g102178/)等|
|4x15mmスペーサー|9|[遊舎工房](https://shop.yushakobo.jp/products/a0800c2?_pos=1&_sid=19dbc8a58&_ss=r&variant=37665435484321)、[ヒロスギネット](https://www.hirosugi-net.co.jp/shop/g/g2404/)|
|ポロンスポンジシート|8|[モノタロウ](https://www.monotaro.com/p/1871/7195/)|
|予備|1|5mm幅に切ってお使いください|
|ゴム足|6|[遊舎工房](https://shop.yushakobo.jp/collections/all-keyboard-parts/products/a0800ur-01-6?variant=37665431060641)、100円ショップ、Amazon等|

### 必要なもの
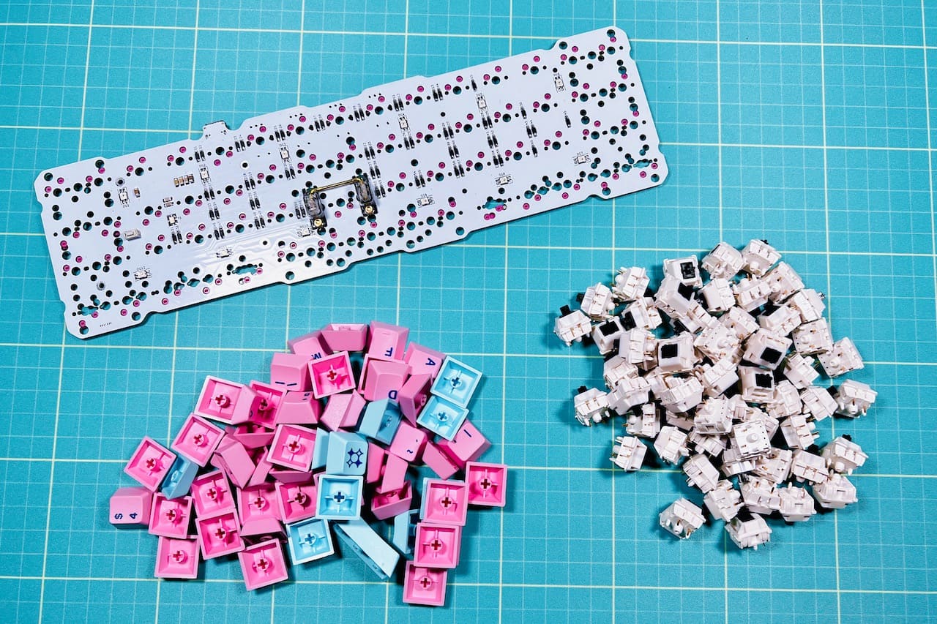
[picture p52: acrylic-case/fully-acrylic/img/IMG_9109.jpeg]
  
|部品名|||
|-|-|-|
|はんだ付け済みメインボード|キースイッチ|キーキャップ|

### 工具（必要に応じて準備してください）
|||
|-|-|
|精密ドライバー|プラス|
|静電防止手袋|組み立て中に指紋が付くのを防げます。|
|アクリサンデー ポリケアF70|指紋を拭いたりホコリを付きにくくできます。|
|アクリサンデー 研磨剤|側面を磨いてツルツルにしたり、細かい傷を消すことができます。|

## 組み立て
 
トッププレートにポロンスポンジシートを貼り付けます。切断面に納得がいかない場合は予備から切り出してください。
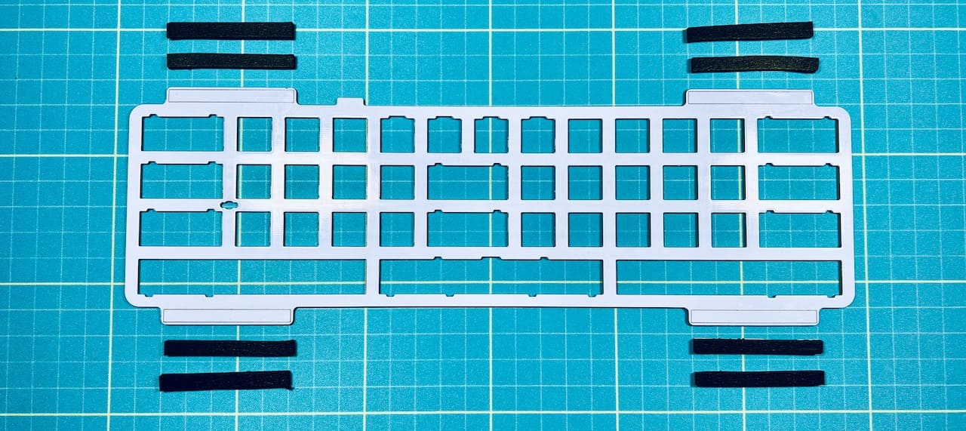
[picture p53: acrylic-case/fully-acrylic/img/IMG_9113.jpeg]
  
キースイッチをトッププレートに取り付け、メインボードのソケットに差し込みます。
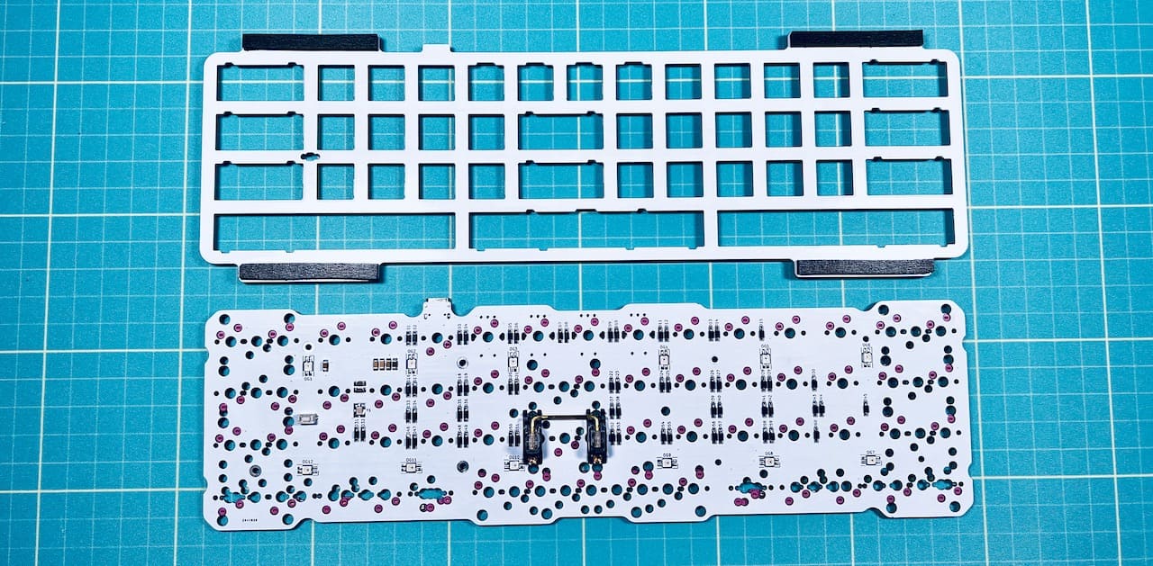
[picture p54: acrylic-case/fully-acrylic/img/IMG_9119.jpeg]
  
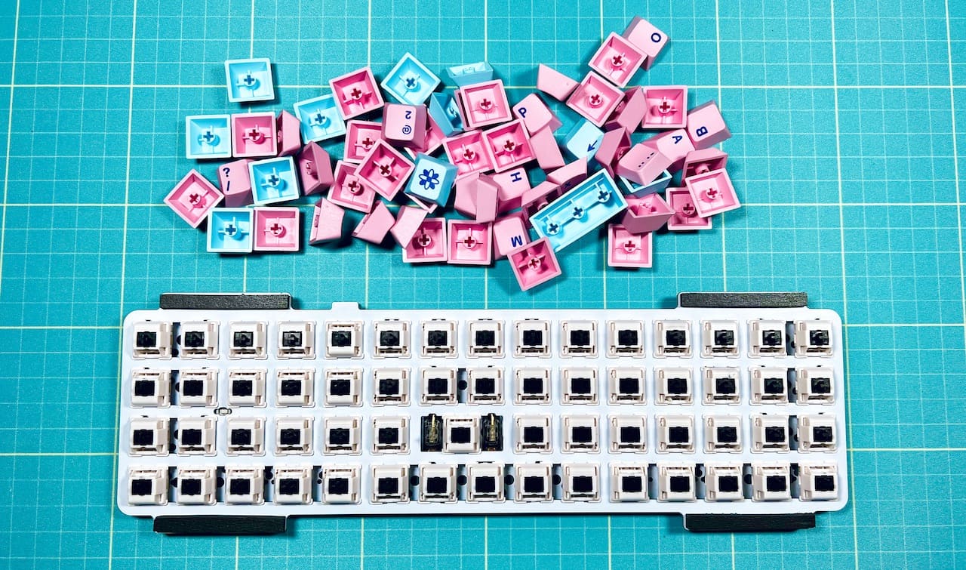
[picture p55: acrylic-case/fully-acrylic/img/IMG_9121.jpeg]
  
キーキャップを付けました。
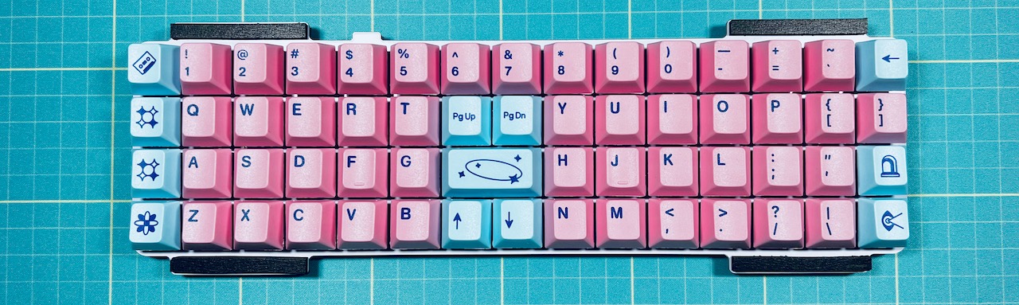
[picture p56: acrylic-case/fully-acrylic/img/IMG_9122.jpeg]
  
 
アクリルケースはキットをご購入の場合は仮組みされています。発注した場合も一度ケースとして組み立てられるか確認すると安全です。 
プレートの順番がわからなくなった場合はこちらを参考にしてください。
 - [プレート一覧](plates.md)
  
表面のネジを外します。  
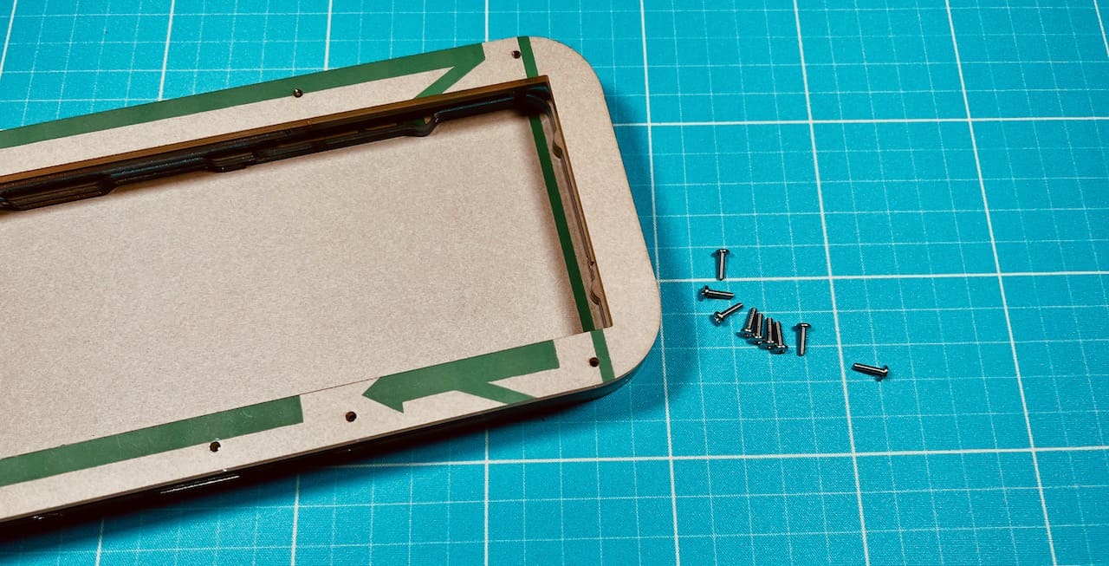
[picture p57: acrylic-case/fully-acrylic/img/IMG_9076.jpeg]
  
裏返してスペーサーごと底のプレートを抜き取ります。  
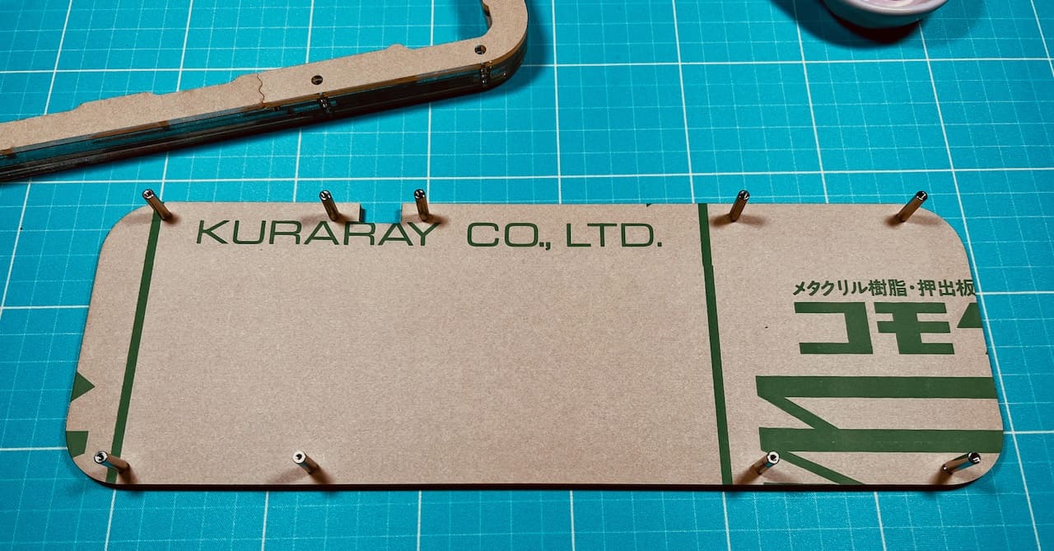
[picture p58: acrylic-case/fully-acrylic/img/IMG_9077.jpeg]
  
ネジを外して底のプレートからスペーサーを取り除いたら保護フィルムを剥がし、ふたたびネジでスペーサーを取り付けます。ネジを締めきらず、スペーサーが浮いている状態にするとここから先の作業が楽になります。 
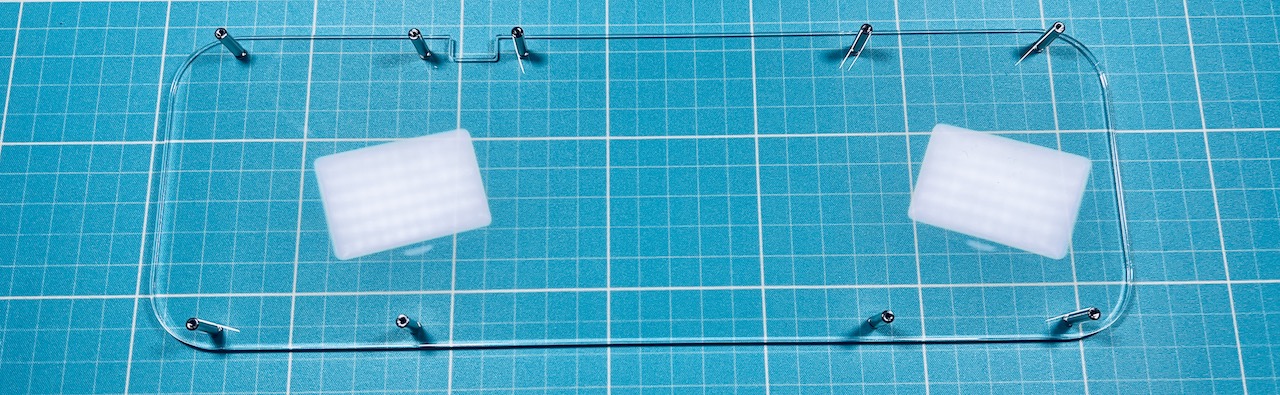
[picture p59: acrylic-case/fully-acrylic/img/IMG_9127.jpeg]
  
  
保護フィルムを外しつつプレートを乗せていきます。  
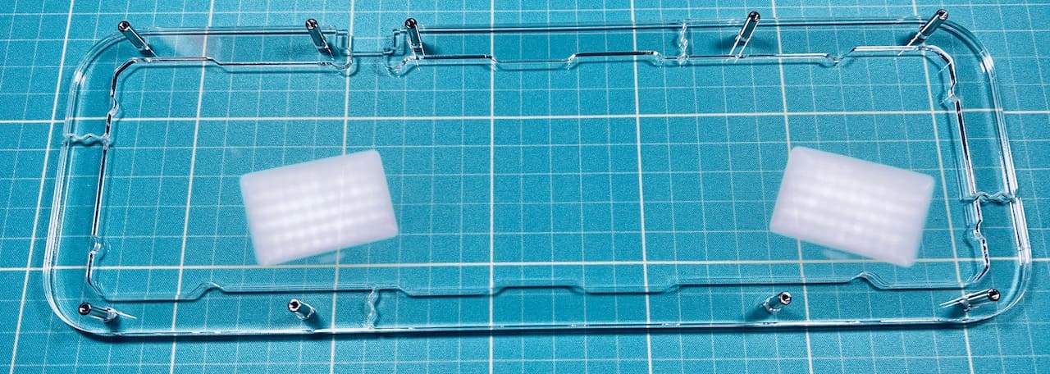
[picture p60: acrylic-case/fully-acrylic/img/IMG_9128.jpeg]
  
  
  
  
3層目まで乗せたらトッププレートを乗せて2層目で挟み込みます。
  
1層目をネジで止め、ゴム足を貼ったら完成です。
  
  
 

## 販売ページ
- [BOOTH](https://tarohayashi.booth.pm/items/3672079)

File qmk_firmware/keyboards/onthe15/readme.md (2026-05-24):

# On the 15
- Manual: https://github.com/Taro-Hayashi/On-the-15/blob/main/README.md
- Yushakobo: https://shop.yushakobo.jp/en/products/4994?variant=43917315539175
- BOOTH: https://tarohayashi.booth.pm/items/3657566  



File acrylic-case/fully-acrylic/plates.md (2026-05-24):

## プレート一覧
上から順です。表裏があります。  
### 1層目
一枚板で長方形に切り抜かれています。ネジ穴が小さいです。  
  
### 2層目
長方形に切り抜かれていて、4パーツに分かれています。  
別売りのパステルミドルプレートはこれの代わりに使います。 
   
### 3層目
4パーツに分かれています。  
トッププレート型の形に切り抜かれています。  
  
### 4層目
4パーツに分かれています。  
3層目との違いは接合部分の位置です。  
  
### 5層目
5パーツに分かれています。  
内側がメインボード型に切り抜かれていてUSB用の隙間（狭）があります。  
  
### 6層目
5パーツに分かれています。  
内側がメインボード型に切り抜かれていてUSB用の隙間（広）があります。  
  
### 7層目
一枚板でUSB用の隙間（狭）があります。  


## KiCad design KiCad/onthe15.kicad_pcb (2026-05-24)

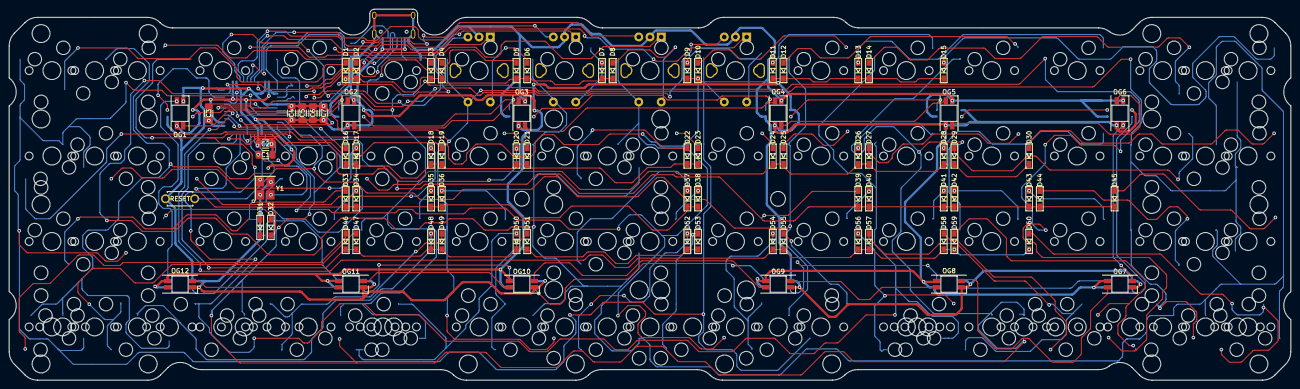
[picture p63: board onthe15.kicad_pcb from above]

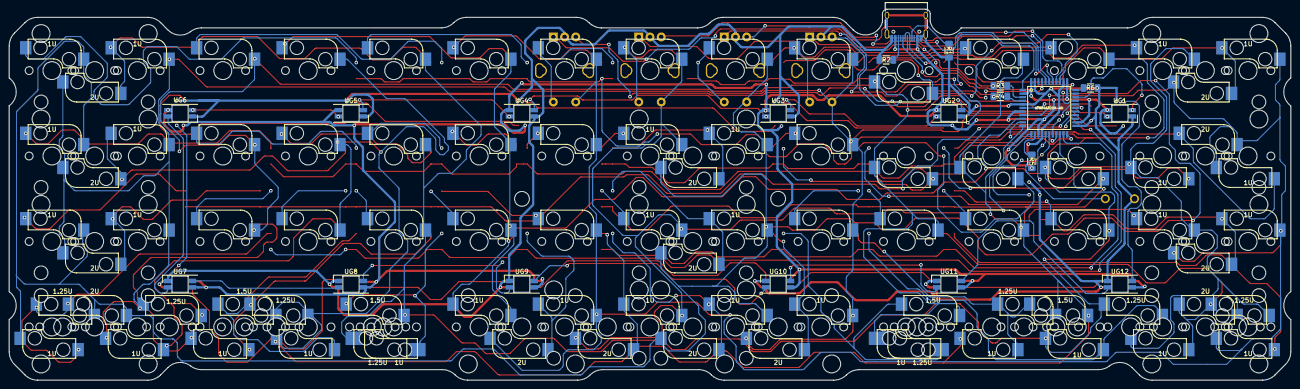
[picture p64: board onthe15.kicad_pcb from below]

Board: 2 copper layers, 285.8 x 82.7 mm, 193 parts (20 on the bottom side), 121 nets.

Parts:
C1, C2: 22p; C_1206_3216_SMD
C3: 1u; C_1206_3216_SMD
C4, C5, C6: 0.1u; C_1206_3216_SMD
C7: 10u; C_1206_3216_SMD
D1, D2, D3, D4, D5, D6, D7, D8, D9, D10, D11, D12, D13, D14, D15, D16, D17, D18, D19, D20, D21, D22, D23, D24, D25, D26, D27, D28, D29, D30, D31, D32, D33, D34, D35, D36, D37, D38, D39, D40, D41, D42, D43, D44, D45, D46, D47, D48, D49, D50, D51, D52, D53, D54, D55, D56, D57, D58, D59, D60: D; Diode_SMD
H5, H6: Hole; Hole_3.3mm_Spacer
J1: USB_C_Receptacle_USB2.0
OG1, OG2, OG3, OG4, OG5, OG6, OG7, OG8, OG9, OG10, OG11, OG12: YS-SK6812MINI-E_overglow; YS-SK6812MINI-E_Undergrow_NOHOLE
R1, R2: 5.1k; R_1206_3216_SMD
R3, R4: 22; R_1206_3216_SMD
R5, R6: 10k; R_1206_3216_SMD
RE1, RE2, RE3, RE4: Rotary_Encoder; RotaryEncoder
RST1: ResetSW
SW1, SW2, SW19, SW20, SW36, SW37, SW38, SW62, SW66, SW67, SW71: 2U; MXOnly-2U-FLIPPED-Hotswap-LED
SW3, SW4, SW16, SW17, SW21, SW22, SW27, SW28, SW34, SW35, SW39, SW40, SW45, SW46, SW52, SW53, SW72, SW73, SW74, SW75, SW76, SW77, SW78, SW79, SW80, SW81, SW82, SW83, SW84, SW85, SW86: 1U; MXOnly-1U-Hotswap
SW5, SW6, SW7, SW8, SW9, SW10, SW11, SW12, SW13, SW14, SW15, SW23, SW24, SW25, SW26, SW29, SW30, SW31, SW32, SW33, SW41, SW42, SW43, SW44, SW47, SW48, SW49, SW50, SW51: SW_PUSH; MXOnly-1U-Hotswap
SW18, SW65, SW68: 2U; MXOnly-2U-Hotswap-ReversedStabilizers
SW54, SW56, SW57, SW58, SW59, SW61: 1.25U; MXOnly-1.25U-Hotswap
SW55, SW60: 1.25U; MXOnly-1.25U-Hotswap-Reverse
SW63, SW64, SW69, SW70: 1.5U; MXOnly-1.5U-Hotswap
U1: ATMEGA32U4-AU
UG1, UG2, UG3, UG4, UG5, UG6, UG7, UG8, UG9, UG10, UG11, UG12: YS-SK6812MINI-E_underglow; YS-SK6812MINI-E_Undergrow
Y1: Crystal; Crystal_3225_SMD

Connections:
GND: C1.2, C2.2, C3.2, C4.2, C5.2, C6.2, C7.2, J1.A1 (GND), J1.A12 (GND), J1.B1 (GND), J1.B12 (GND), J1.S1 (SHIELD), OG1.3 (VSS), OG2.3 (VSS), OG3.3 (VSS), OG4.3 (VSS), OG5.3 (VSS), OG6.3 (VSS), OG7.3 (VSS), OG8.3 (VSS), OG9.3 (VSS), OG10.3 (VSS), OG11.3 (VSS), OG12.3 (VSS), R1.2, R2.2, R6.2, RE1.C, RE2.C, RE3.C, RE4.C, RST1.2, U1.5 (UGND), U1.15 (GND), U1.23 (GND), U1.35 (GND), U1.43 (GND), UG1.3 (VSS), UG2.3 (VSS), UG3.3 (VSS), UG4.3 (VSS), UG5.3 (VSS), UG6.3 (VSS), UG7.3 (VSS), UG8.3 (VSS), UG9.3 (VSS), UG10.3 (VSS), UG11.3 (VSS), UG12.3 (VSS), Y1.2, Y1.4
unnamed: C3.1, U1.6 (UCAP)
unnamed: D1.2 (A), SW1.2, SW3.2
unnamed: D2.2 (A), SW4.2
unnamed: D3.2 (A), SW5.2
unnamed: D4.2 (A), SW6.2
unnamed: D5.2 (A), SW7.2
unnamed: D10.2 (A), SW12.2
unnamed: D11.2 (A), SW13.2
unnamed: D12.2 (A), SW14.2
unnamed: D13.2 (A), SW15.2
unnamed: D14.2 (A), SW2.2, SW16.2
unnamed: D15.2 (A), SW17.2
unnamed: D16.2 (A), SW18.2, SW21.2
unnamed: D17.2 (A), SW22.2
unnamed: D18.2 (A), SW23.2
unnamed: D19.2 (A), SW24.2
unnamed: D20.2 (A), SW25.2
unnamed: D21.2 (A), SW26.2
unnamed: D22.2 (A), SW19.2, SW27.2
unnamed: D23.2 (A), SW28.2
unnamed: D24.2 (A), SW29.2
unnamed: D25.2 (A), SW30.2
unnamed: D26.2 (A), SW31.2
unnamed: D27.2 (A), SW32.2
unnamed: D28.2 (A), SW33.2
unnamed: D29.2 (A), SW20.2, SW34.2
unnamed: D30.2 (A), SW35.2
unnamed: D31.2 (A), SW36.2, SW39.2
unnamed: D32.2 (A), SW40.2
unnamed: D33.2 (A), SW41.2
unnamed: D34.2 (A), SW42.2
unnamed: D35.2 (A), SW43.2
unnamed: D36.2 (A), SW44.2
unnamed: D37.2 (A), SW37.2, SW45.2
unnamed: D38.2 (A), SW46.2
unnamed: D39.2 (A), SW47.2
unnamed: D40.2 (A), SW48.2
unnamed: D41.2 (A), SW49.2
unnamed: D42.2 (A), SW50.2
unnamed: D43.2 (A), SW51.2
unnamed: D44.2 (A), SW38.2, SW52.2
unnamed: D45.2 (A), SW53.2
unnamed: D46.2 (A), SW72.2
unnamed: D47.2 (A), SW54.2, SW62.2, SW73.2
unnamed: D48.2 (A), SW55.2, SW74.2
unnamed: D49.2 (A), SW56.2, SW63.2, SW75.2
unnamed: D50.2 (A), SW57.2, SW64.2, SW76.2
unnamed: D51.2 (A), SW65.2, SW77.2
unnamed: D52.2 (A), SW66.2, SW78.2
unnamed: D53.2 (A), SW67.2, SW79.2
unnamed: D54.2 (A), SW68.2, SW80.2
unnamed: D55.2 (A), SW81.2
unnamed: D56.2 (A), SW58.2, SW69.2, SW82.2
unnamed: D57.2 (A), SW59.2, SW70.2, SW83.2
unnamed: D58.2 (A), SW84.2
unnamed: D59.2 (A), SW60.2, SW85.2
unnamed: D60.2 (A), SW61.2, SW71.2, SW86.2
unnamed: J1.A5 (CC1), R1.1
unnamed: J1.A6 (D+), J1.B6 (D+), R4.2
unnamed: J1.A7 (D-), J1.B7 (D-), R3.2
unnamed: J1.B5 (CC2), R2.1
unnamed: OG1.2 (DOUT), OG2.4 (DIN)
unnamed: OG1.4 (DIN), UG12.2 (DOUT)
unnamed: OG2.2 (DOUT), OG3.4 (DIN)
unnamed: OG3.2 (DOUT), OG4.4 (DIN)
unnamed: OG4.2 (DOUT), OG5.4 (DIN)
unnamed: OG5.2 (DOUT), OG6.4 (DIN)
unnamed: OG6.2 (DOUT), OG7.4 (DIN)
unnamed: OG7.2 (DOUT), OG8.4 (DIN)
unnamed: OG8.2 (DOUT), OG9.4 (DIN)
unnamed: OG10.2 (DOUT), OG11.4 (DIN)
unnamed: OG9.2 (DOUT), OG10.4 (DIN)
unnamed: OG11.2 (DOUT), OG12.4 (DIN)
unnamed: R6.1, U1.33 (PE2)
unnamed: UG1.2 (DOUT), UG2.4 (DIN)
unnamed: UG2.2 (DOUT), UG3.4 (DIN)
unnamed: UG3.2 (DOUT), UG4.4 (DIN)
unnamed: UG4.2 (DOUT), UG5.4 (DIN)
unnamed: UG5.2 (DOUT), UG6.4 (DIN)
unnamed: UG6.2 (DOUT), UG7.4 (DIN)
unnamed: UG7.2 (DOUT), UG8.4 (DIN)
unnamed: UG8.2 (DOUT), UG9.4 (DIN)
unnamed: UG10.2 (DOUT), UG11.4 (DIN)
unnamed: UG9.2 (DOUT), UG10.4 (DIN)
unnamed: UG11.2 (DOUT), UG12.4 (DIN)
VCC: C4.1, C5.1, C6.1, C7.1, J1.A4 (VBUS), J1.A9 (VBUS), J1.B4 (VBUS), J1.B9 (VBUS), OG1.1 (VDD), OG2.1 (VDD), OG3.1 (VDD), OG4.1 (VDD), OG5.1 (VDD), OG6.1 (VDD), OG7.1 (VDD), OG8.1 (VDD), OG9.1 (VDD), OG10.1 (VDD), OG11.1 (VDD), OG12.1 (VDD), R5.2, U1.2 (UVCC), U1.7 (VBUS), U1.14 (VCC), U1.24 (AVCC), U1.34 (VCC), U1.44 (AVCC), UG1.1 (VDD), UG2.1 (VDD), UG3.1 (VDD), UG4.1 (VDD), UG5.1 (VDD), UG6.1 (VDD), UG7.1 (VDD), UG8.1 (VDD), UG9.1 (VDD), UG10.1 (VDD), UG11.1 (VDD), UG12.1 (VDD)
col0: RE4.S1, SW1.1, SW3.1, SW11.1, SW18.1, SW21.1, SW29.1, SW36.1, SW39.1, SW47.1, SW68.1, SW72.1, SW80.1, U1.8 (PB0)
col1: SW4.1, SW12.1, SW22.1, SW30.1, SW40.1, SW48.1, SW54.1, SW62.1, SW73.1, SW81.1, U1.9 (PB1)
col2: SW5.1, SW13.1, SW23.1, SW31.1, SW41.1, SW49.1, SW55.1, SW58.1, SW69.1, SW74.1, SW82.1, U1.10 (PB2)
col3: SW6.1, SW14.1, SW24.1, SW32.1, SW42.1, SW50.1, SW56.1, SW59.1, SW63.1, SW70.1, SW75.1, SW83.1, U1.11 (PB3)
col4: SW7.1, SW15.1, SW25.1, SW33.1, SW43.1, SW51.1, SW57.1, SW64.1, SW76.1, SW84.1, U1.28 (PB4)
col5: RE1.S1, SW2.1, SW8.1, SW16.1, SW20.1, SW26.1, SW34.1, SW38.1, SW44.1, SW52.1, SW60.1, SW65.1, SW77.1, SW85.1, U1.29 (PB5)
col6: RE2.S1, SW9.1, SW17.1, SW19.1, SW27.1, SW35.1, SW37.1, SW45.1, SW53.1, SW61.1, SW66.1, SW71.1, SW78.1, SW86.1, U1.30 (PB6)
col7: RE3.S1, SW10.1, SW28.1, SW46.1, SW67.1, SW79.1, U1.12 (PB7)
d+: R4.1, U1.4 (D+)
d-: R3.1, U1.3 (D-)
led: U1.31 (PC6), UG1.4 (DIN)
reset: R5.1, RST1.1, U1.13 (~RESET)
rot1a: RE1.A, U1.32 (PC7)
rot1b: RE1.B, U1.1 (PE6)
rot1s2: D6.2 (A), RE1.S2, SW8.2
rot2a: RE2.A, U1.41 (PF0)
rot2b: RE2.B, U1.40 (PF1)
rot2s2: D7.2 (A), RE2.S2, SW9.2
rot3a: RE3.A, U1.39 (PF4)
rot3b: RE3.B, U1.38 (PF5)
rot3s2: D8.2 (A), RE3.S2, SW10.2
rot4a: RE4.A, U1.37 (PF6)
rot4b: RE4.B, U1.36 (PF7)
rot4s2: D9.2 (A), RE4.S2, SW11.2
row0: D1.1 (K), D2.1 (K), D3.1 (K), D4.1 (K), D5.1 (K), D6.1 (K), D7.1 (K), D8.1 (K), U1.18 (PD0)
row1: D16.1 (K), D17.1 (K), D18.1 (K), D19.1 (K), D20.1 (K), D21.1 (K), D22.1 (K), D23.1 (K), U1.19 (PD1)
row2: D31.1 (K), D32.1 (K), D33.1 (K), D34.1 (K), D35.1 (K), D36.1 (K), D37.1 (K), D38.1 (K), U1.20 (PD2)
row3: D46.1 (K), D47.1 (K), D48.1 (K), D49.1 (K), D50.1 (K), D51.1 (K), D52.1 (K), D53.1 (K), U1.21 (PD3)
row4: D9.1 (K), D10.1 (K), D11.1 (K), D12.1 (K), D13.1 (K), D14.1 (K), D15.1 (K), U1.25 (PD4)
row5: D24.1 (K), D25.1 (K), D26.1 (K), D27.1 (K), D28.1 (K), D29.1 (K), D30.1 (K), U1.22 (PD5)
row6: D39.1 (K), D40.1 (K), D41.1 (K), D42.1 (K), D43.1 (K), D44.1 (K), D45.1 (K), U1.26 (PD6)
row7: D54.1 (K), D55.1 (K), D56.1 (K), D57.1 (K), D58.1 (K), D59.1 (K), D60.1 (K), U1.27 (PD7)
xtal1: C1.1, U1.17 (XTAL1), Y1.3
xtal2: C2.1, U1.16 (XTAL2), Y1.1

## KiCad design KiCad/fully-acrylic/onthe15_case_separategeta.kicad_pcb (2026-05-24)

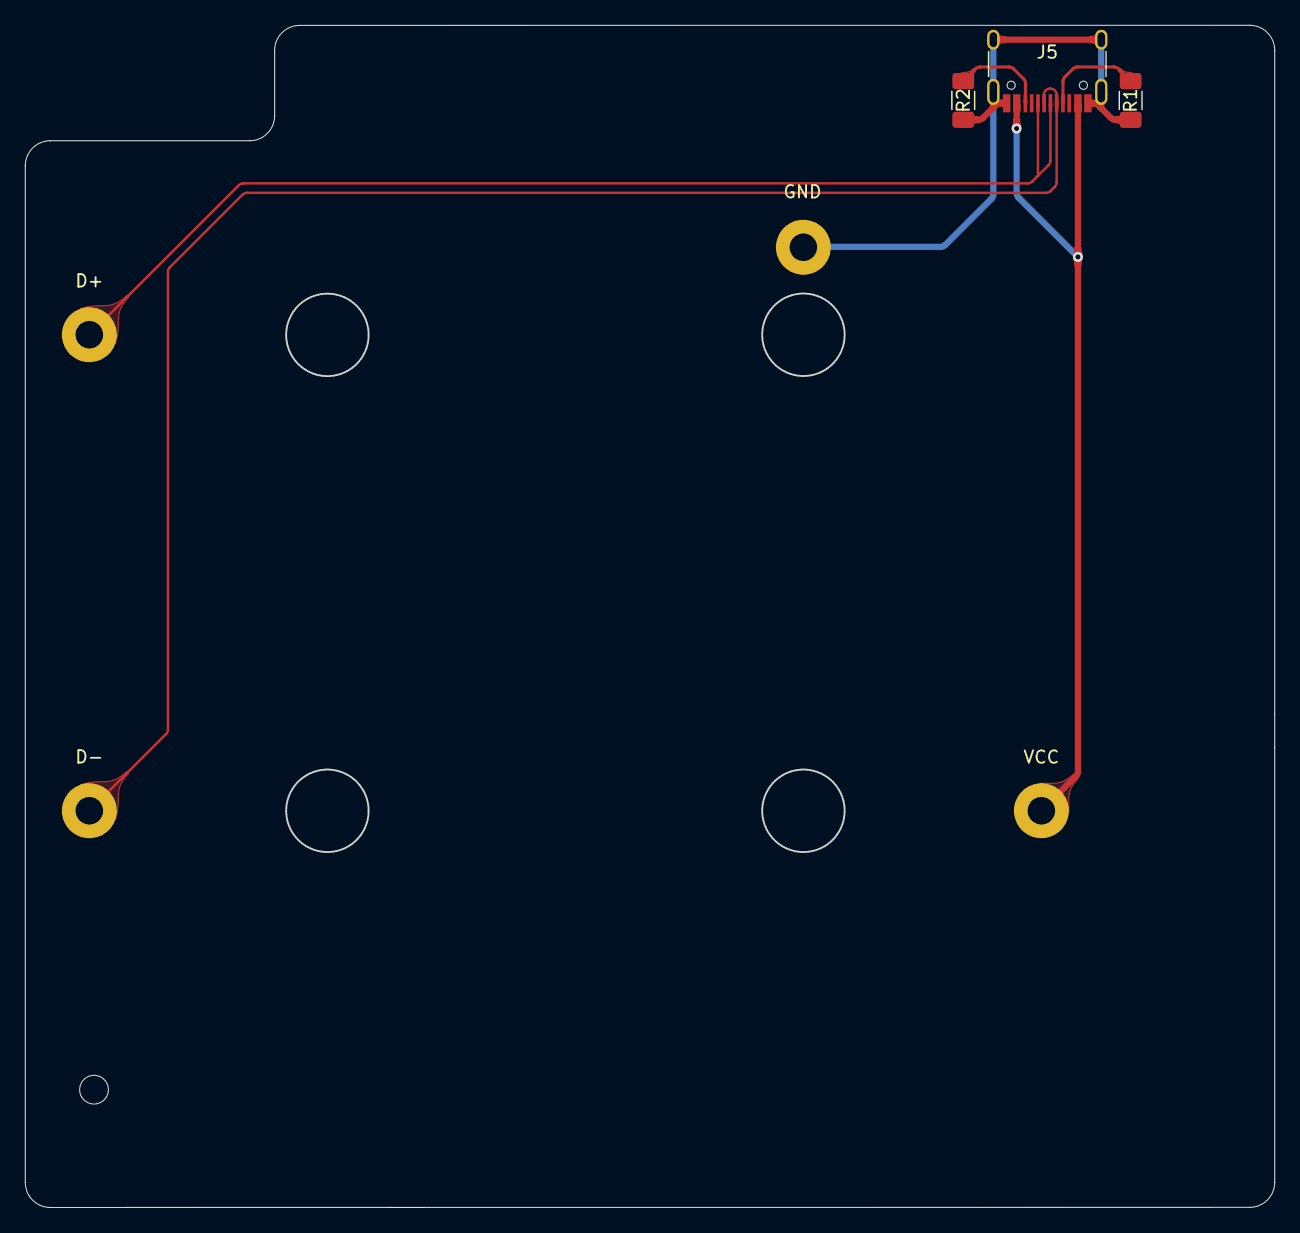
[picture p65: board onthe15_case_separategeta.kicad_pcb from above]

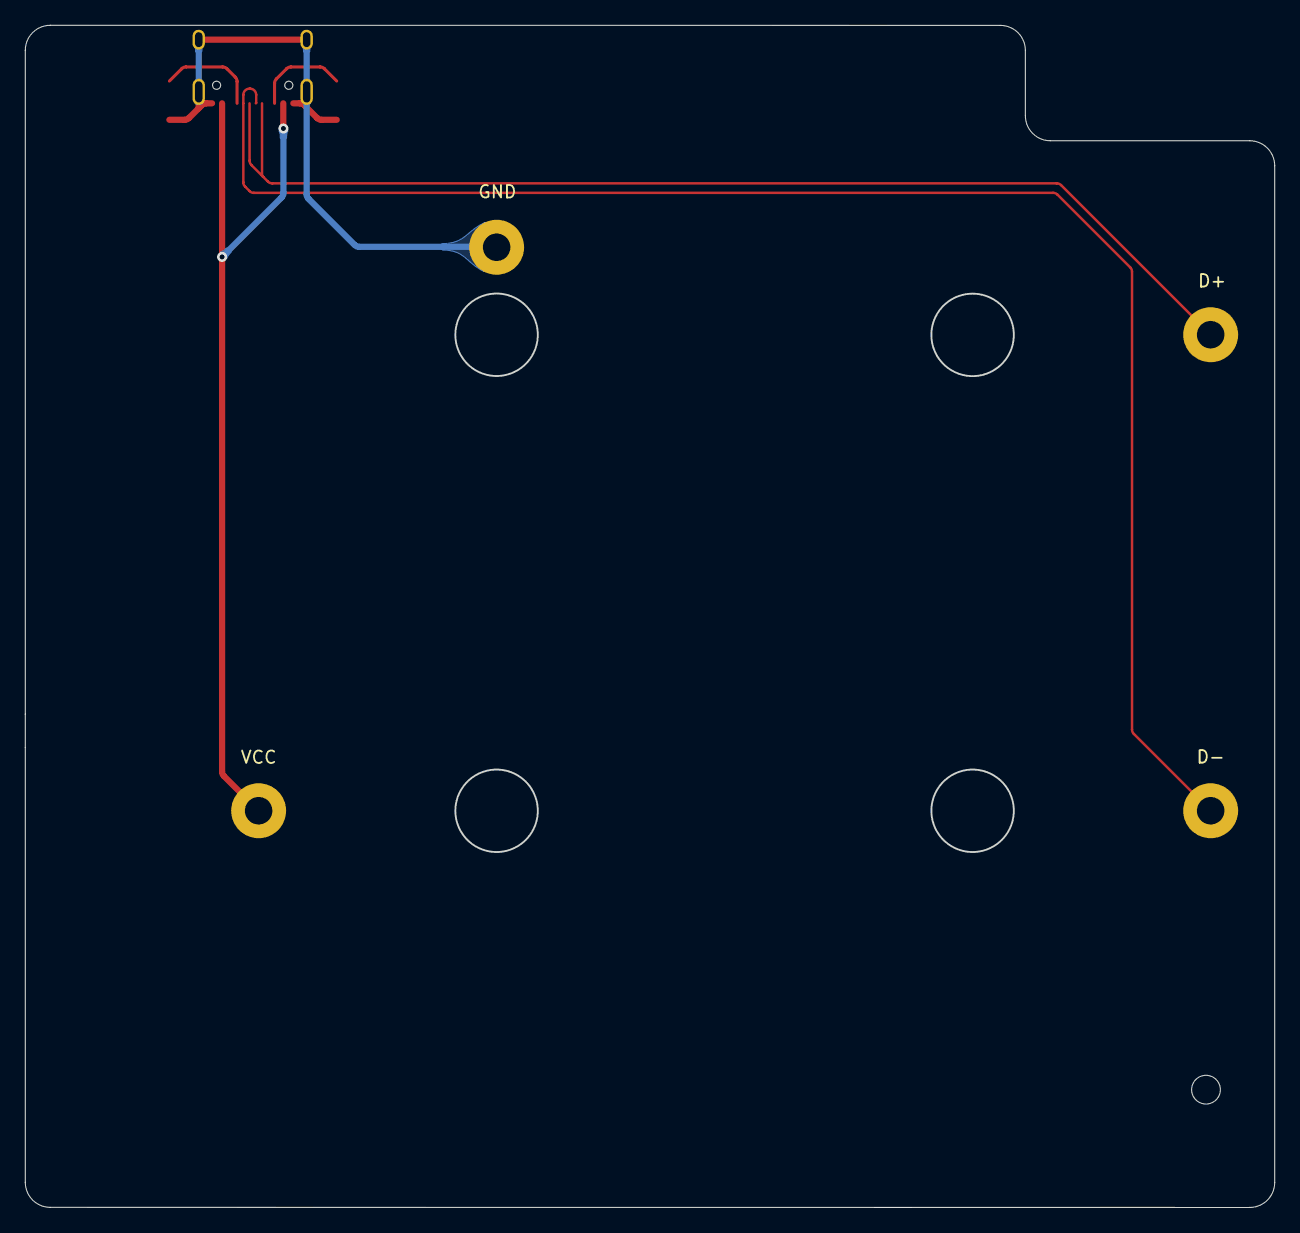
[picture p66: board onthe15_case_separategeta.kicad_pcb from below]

Board: 2 copper layers, 100.0 x 94.6 mm, 10 parts (6 on the bottom side), 6 nets.

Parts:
HOLE1, HOLE1#2, HOLE4: Hole_5x2.3_6; Hole_5x2.5_7
J1, J2, J3, J4: Conn_01x01_Female; Conn_2.2mm_M2
J5: USB_C_Receptacle_USB2.0
R1, R2: 5.1k; R_1206_3216_SMD

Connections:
D+: J4.1, J5.A6 (D+), J5.B6 (D+)
D-: J3.1, J5.A7 (D-), J5.B7 (D-)
GND: J2.1, J5.A1 (GND), J5.A12 (GND), J5.B1 (GND), J5.B12 (GND), J5.S1 (SHIELD), R1.2, R2.2
unnamed: J5.A5 (CC1), R1.1
unnamed: J5.B5 (CC2), R2.1
VCC: J1.1, J5.A4 (VBUS), J5.A9 (VBUS), J5.B4 (VBUS), J5.B9 (VBUS)

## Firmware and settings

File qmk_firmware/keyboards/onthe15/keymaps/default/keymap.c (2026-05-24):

// Copyright 2022 Taro Hayashi (@w_vwbw)
// SPDX-License-Identifier: GPL-2.0-or-later

#include QMK_KEYBOARD_H
#include "lib/add_keycodes.h"

enum layer_names {
  BASE = 0,
  LOWER,
  LIGHT = 5,
};

const uint16_t PROGMEM keymaps[][MATRIX_ROWS][MATRIX_COLS] = {
    [BASE] = LAYOUT(
      KC_ESC,  KC_1, KC_2, KC_3, KC_4, KC_5, KC_MINS, KC_QUOT, KC_EQL, KC_6, KC_7, KC_8, KC_9, KC_0, KC_BSPC,
      KC_TAB,  KC_Q, KC_W, KC_E, KC_R, KC_T, KC_LBRC, KC_UP, KC_RBRC, KC_Y, KC_U, KC_I, KC_O, KC_P, KC_BSLS,
      CMD_CTL, KC_A, KC_S, KC_D, KC_F, KC_G, KC_LEFT,KC_DOWN,KC_RIGHT,KC_H, KC_J, KC_K, KC_L, KC_SCLN, KC_ENT,
      KC_LSFT, KC_Z, KC_X, KC_C, KC_V, LALT_T(KC_B), LT(LOWER, KC_SPC), LT(LOWER, KC_SPC), LGUI_T(KC_GRV),  KC_N, KC_M, KC_COMM, KC_DOT,  KC_SLSH, KC_RSFT
    ),
    [LOWER] = LAYOUT(
      XXXXXXX, KC_F1,   KC_F2,   KC_F3,   KC_F4,   KC_F5,   XXXXXXX, XXXXXXX, XXXXXXX, KC_F6,   KC_F7,   KC_F8,   KC_F9,   KC_F10,  KC_DEL,
      XXXXXXX, XXXXXXX, XXXXXXX, XXXXXXX, XXXXXXX, XXXXXXX, LSFT(KC_9), LSFT(KC_0), XXXXXXX, XXXXXXX, XXXXXXX, XXXXXXX, XXXXXXX, XXXXXXX, KC_QUOT,
      XXXXXXX, XXXXXXX, XXXXXXX, XXXXXXX, XXXXXXX, XXXXXXX, XXXXXXX, XXXXXXX, XXXXXXX, XXXXXXX, XXXXXXX, XXXXXXX, XXXXXXX, KC_UP,   XXXXXXX,
      XXXXXXX, XXXXXXX, XXXXXXX, XXXXXXX, XXXXXXX, XXXXXXX, LT(LOWER, KC_SPC), LT(LOWER, KC_SPC), XXXXXXX, XXXXXXX, XXXXXXX, XXXXXXX, KC_LEFT, KC_DOWN, KC_RGHT
    )
};

const uint16_t PROGMEM encoder_map[][NUM_ENCODERS][2] = {
    [BASE] =   {
        ENCODER_CCW_CW(KC_A, KC_B),
        ENCODER_CCW_CW(KC_C, KC_D),
        ENCODER_CCW_CW(KC_E, KC_F),
        ENCODER_CCW_CW(KC_G, KC_H)
        },
    [LOWER] = {
        ENCODER_CCW_CW(XXXXXXX, XXXXXXX),
        ENCODER_CCW_CW(XXXXXXX, XXXXXXX),
        ENCODER_CCW_CW(XXXXXXX, XXXXXXX),
        ENCODER_CCW_CW(XXXXXXX, XXXXXXX)
        }
};
